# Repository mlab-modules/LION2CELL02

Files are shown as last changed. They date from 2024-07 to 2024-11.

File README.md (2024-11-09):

# LION2CELL02 - Dual-cell Li-Ion BMS with I2C interface and USB-C charging.

The LION2CELL02 module is designed to manage the charging and protection of the 2-cell Li-Ion battery stack. It incorporates advanced safe and efficient battery management features, utilizing the BQ40Z50-R2 fuel gauge and BQ25792 battery charger ICs.

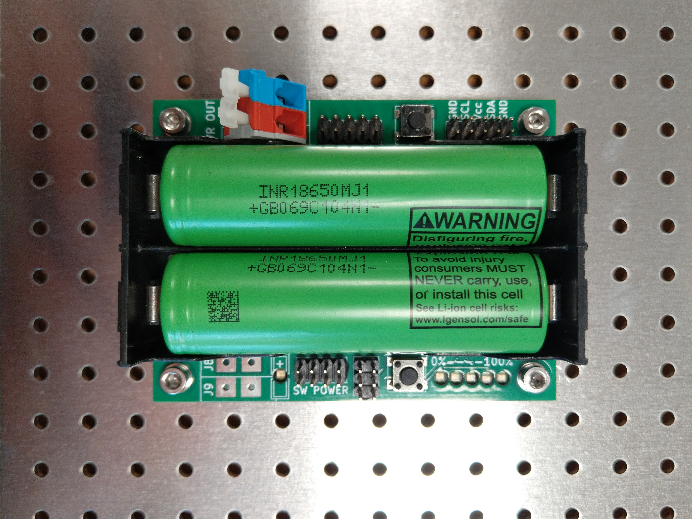
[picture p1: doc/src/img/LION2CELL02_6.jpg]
LION2CELL02 mounted on MLAB base


## Features

The LION2CELL02 module include USB-C connector for quick charge connection. This allows for easy integration with USB-C power sources.

### BQ40Z50-R2 - Fuel Gauge

- Utilizes Impedance Track™ technology for accurate charge measurement.
- High-side protection N-FETs control.
- Integrated cell balancing during charging or at rest.
- Programmable protection features (voltage, current, temperature, charge timeout).
- JEITA, enhanced charging, and adaptive charging algorithms.
- Supports TURBO Mode 2.0 and Battery Trip Point (BTP).
- LED display for battery status.
- SMBus v1.1 interface for communication with the charger and host systems.

### BQ25792 Battery Charger

- Supports USB BC 1.2 charging standard.
- High-efficiency buck-boost charging for Li-Ion batteries.
- Programmable input current, charge current, and charge voltage.
- Integrated power path management.
- Protection features including overvoltage, undervoltage, overcurrent, and thermal protection.
- Low quiescent current for extended battery life.

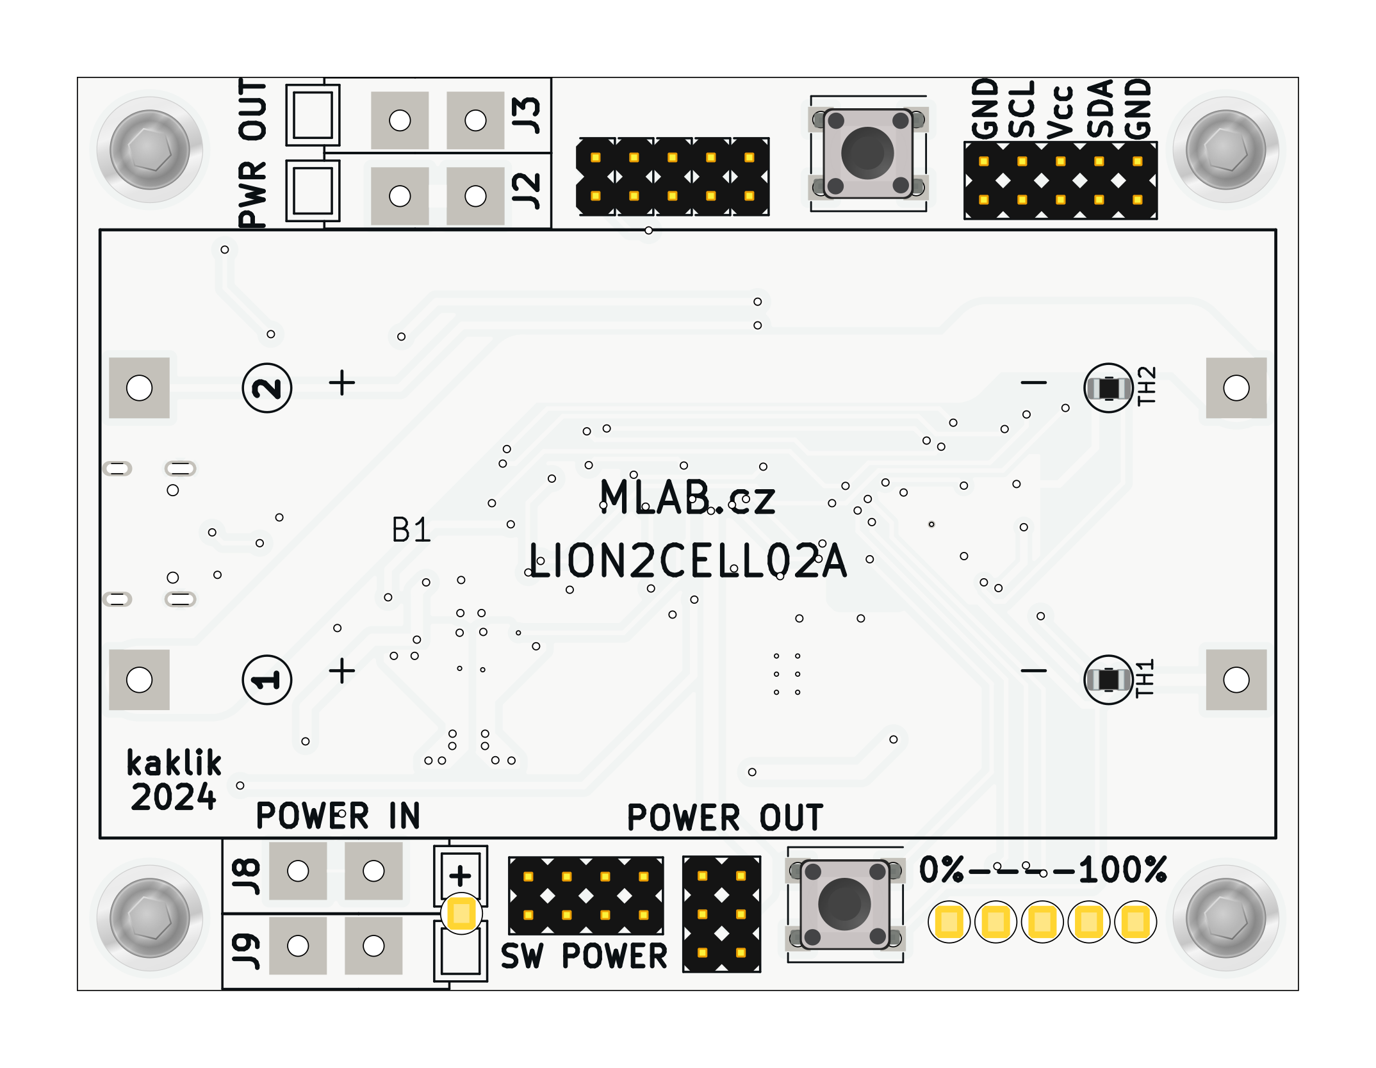
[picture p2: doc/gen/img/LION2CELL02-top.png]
LION2CELL02 top


## Power Delivery

The module supports BC 1.2 for charging. For the full USB Power Delivery (PD) support, an external USB PD controller is required. The MLAB [USBPDSINK01](https://www.mlab.cz/module/USBPDSINK01/) module can be used to enable PD functionality.

## Usage Instructions

1. Equip the LION2CELL02 module with pair of the suitable 16850 Li-Ion batteries.
2. Connect a USB-C power source to the module. For standard charging, ensure the power source complies with BC 1.2.
3. For USB PD, connect the USBPDSINK01 module to enable PD negotiation and charging.
4. Monitor the LED indicators for battery and charging status.
5. Connect to an MCU and use I2C/smbus for advanced features. 

## Safety and Protection

- The module includes multiple layers of protection for voltage, current, and temperature to ensure safe operation.
- Integrated cell balancing ensures equal charging across all cells, preventing overcharge and extending battery life.

## Applications

- UPS/battery backup systems
- Stand-alone measurement devices
- Scientific equipment

## Additional Resources

For further information, refer to the datasheets:
- [BQ40Z50-R2 Datasheet](https://www.ti.com/product/BQ40Z50-R2)
- [BQ25792 Datasheet](https://www.ti.com/product/BQ25792)

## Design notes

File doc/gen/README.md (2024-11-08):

# PCB

Board size: 80.77x60.45 mm (3.18x2.38 inches)

- This is the size of the rectangle that contains the board
- Thickness: 1.6 mm (63 mils)
- Material: FR4
- Finish: None
- Layers: 2
- Copper thickness: 35 µm

Solder mask: TOP / BOTTOM

- Color: Green

Silk screen: TOP / BOTTOM

- Color: White

Stackup:

| Name | Type | Color | Thickness [µm]| Material | Er | Loss tan |
|---|---|---|---|---|---|---|
| F.SilkS | Top Silk Screen | | | | | |
| F.Mask | Top Solder Mask | | 10 | | | |
| F.Cu | copper | | 35 | | | |
| dielectric 1 | core | | 1510 | FR4 | 4.5 | 0.020 |
| B.Cu | copper | | 35 | | | |
| B.Mask | Bottom Solder Mask | | 10 | | | |
| B.Paste | Bottom Solder Paste  | | | | | |
| B.SilkS | Bottom Silk Screen | | | | | |

# Important sizes

Clearance: 0.2 mm (8 mils)

Track width: 0.2 mm (8 mils)

- By design rules: 0.2 mm (8 mils)

Drill: 0.3 mm (12 mils)

- Vias: 0.3 mm (12 mils) [Design: 0.3 mm (12 mils)]
- Pads: 0.3 mm (12 mils)
- The above values are real drill sizes, they add 0.1 mm (4 mils) to plated holes (PTH)

Via: 0.4/0.2 mm (16/8 mils)

- By design rules: 0.4/0.2 mm (16/8 mils)
- Micro via: yes [0.2/0.1 mm (8/4 mils)]
- Buried/blind via: yes
- Total: 91 (thru: 88 buried/blind: 0 micro: 3)

Outer Annular Ring: 0.05 mm (2 mils)

- By design rules: 0.1 mm (4 mils)

Eurocircuits class: 6F
- Using min drill 0.15 mm for an OAR of 0.13 mm

# General stats

Components count: (SMD/THT)

- Top: 2/19 (SMD + THT)
- Bottom: 83/0 (SMD)

Defined tracks:

- 0.2 mm (8 mils)
- 0.25 mm (10 mils)
- 0.3 mm (12 mils)
- 0.4 mm (16 mils)
- 0.5 mm (20 mils)
- 0.6 mm (24 mils)
- 0.8 mm (31 mils)
- 1.5 mm (59 mils)

Used tracks:

- 0.2 mm (8 mils) (195) defined: yes
- 0.3 mm (12 mils) (330) defined: yes
- 0.4 mm (16 mils) (15) defined: yes
- 0.5 mm (20 mils) (103) defined: yes
- 0.6 mm (24 mils) (2) defined: yes
- 0.8 mm (31 mils) (41) defined: yes
- 1.0 mm (39 mils) (52) defined: no
- 1.5 mm (59 mils) (1) defined: yes
- 4.5 mm (177 mils) (6) defined: no

Defined vias:

Used vias:

- 0.4/0.2 mm (16/8 mils) (Count: 3, Aspect: 4.0 A) defined: no
- 0.8/0.4 mm (31/16 mils) (Count: 88, Aspect: 2.0 A) defined: no

Holes (excluding vias):

- 0.2 mm (8 mils) (7)
- 0.65 mm (26 mils) (2)
- 0.89 mm (35 mils) (34)
- 1.0 mm (39 mils) (8)
- 1.3 mm (51 mils) (8)
- 1.6 mm (63 mils) (4)
- 2.7 mm (106 mils) (6)
- 3.0 mm (118 mils) (4)

Oval holes:

- 0.6x1.4 mm (24x55 mils) (2)
- 0.6x1.7 mm (24x67 mils) (2)

Drill tools (including vias and computing adjusts and rounding):

- 0.3 mm (12 mils) (10)
- 0.5 mm (20 mils) (88)
- 0.65 mm (26 mils) (2)
- 0.7 mm (28 mils) (4)
- 1.0 mm (39 mils) (34)
- 1.1 mm (43 mils) (8)
- 1.4 mm (55 mils) (8)
- 1.7 mm (67 mils) (4)
- 2.7 mm (106 mils) (6)
- 3.1 mm (122 mils) (4)

Solder paste stats:

Using a paste with 87.75 % alloy, that has an specific gravity for the alloy of 7.4 g/cm³
and 1.0 g/cm³ for the flux. This paste has an specific gravity of  4.15 g/cm³.

The stencil thickness is  0.12 mm.

| Side | Pads with paste | Area [mm²] | Paste [g] |
|---|---|---|---|
| Top | 4 | 5.51 | 0.03 |
| Bottom | 254 | 338.60 | 1.69 |
| Total  | 258 | 344.11 | 1.71 |

Note: this is just an approximation to the theoretical value. Margins of the solder mask and waste aren't computed.

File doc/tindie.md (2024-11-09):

### MLAB LION2CELL02 - Dual-Cell Li-Ion Battery Management Module

### What is it?

The **MLAB LION2CELL02** is a high-efficiency dual-cell battery management system (BMS) designed to charge and protect a two-cell Li-Ion battery stack. Featuring an I2C interface and a USB-C charging port, the LION2CELL02 integrates easily into systems requiring robust power management. The module is compatible with standard USB BC 1.2 sources.

The LION2CELL02 is pre-configured for **INR18650MJ1** cells, ensuring optimal performance and battery health.

### Why did you make it?

This module was created to simplify the power management and protection requirements where single-cell Li-Ion battery setups are not enougth. It’s tailored to applications requiring reliable charging, safety, and monitoring features, which are essential in embedded systems like IoT devices, portable instruments, and backup power solutions. 

### What makes it special?

- **Dual-cell support and protection**: Charger and Gas-gauge both independently manages charging for two Li-Ion cells, with integrated protection for voltage, current, and temperature.
- **I2C communication**: Allows seamless integration with microcontroller systems for real-time battery status.
- **High-efficiency charging**: Includes the BQ25792 high-efficiency buck-boost charger, ensuring fast and reliable charging from USB-C sources.
- **Advanced cell balancing**: The BQ40Z50-R2 fuel gauge features Impedance Track™ technology for precise capacity measurement and cell balancing, extending battery lifespan.
- **Flexible Power Delivery (PD)**: Compatible with USB BC 1.2 and offers optional USB PD support via an external controller.

### Key Features

- **USB-C Charging**: Supports USB BC 1.2 with an optional external PD controller.
- **Integrated Protections**: Includes overvoltage, undervoltage, overcurrent, and thermal protections.
- **High Precision Fuel Gauge**: Impedance Track™ technology provides real-time capacity and state-of-charge data.
- **I2C Interface**: Connects easily to MCUs for monitoring battery voltage, current, and temperature.
- **LED Indicators**: Visual indicators display charge level and fault conditions.

### Technical Specifications

- **Battery Type**: Li-Ion (configured for INR18650MJ1 cells)
- **Cells Supported**: 2 cells (2S configuration)
- **Charger IC**: Texas Instruments BQ25792
- **Fuel Gauge IC**: Texas Instruments BQ40Z50-R2
- **Input Voltage**: 3.6V to 20V (USB-C)
- **Output Current**: Up to 5A (charging), 3A (USB OTG mode)
- **Communication**: I2C (compatible with SMBus v1.1)
- **Protections**: Overvoltage, undervoltage, overcurrent, overtemperature, cell balancing
- **Dimensions**: Fits standard 6x8 MLAB module footprint

For additional details and configuration options, refer to the datasheets for [BQ40Z50-R2](https://www.ti.com/product/BQ40Z50-R2) and [BQ25792](https://www.ti.com/product/BQ25792).

### Included

- LION2CELL02 module pre-configured
- Two INR18650MJ1 Li-ion cells

### Use Cases

- [Stratospheric baloons](https://github.com/ODZ-UJF-AV-CR/FIK-6)

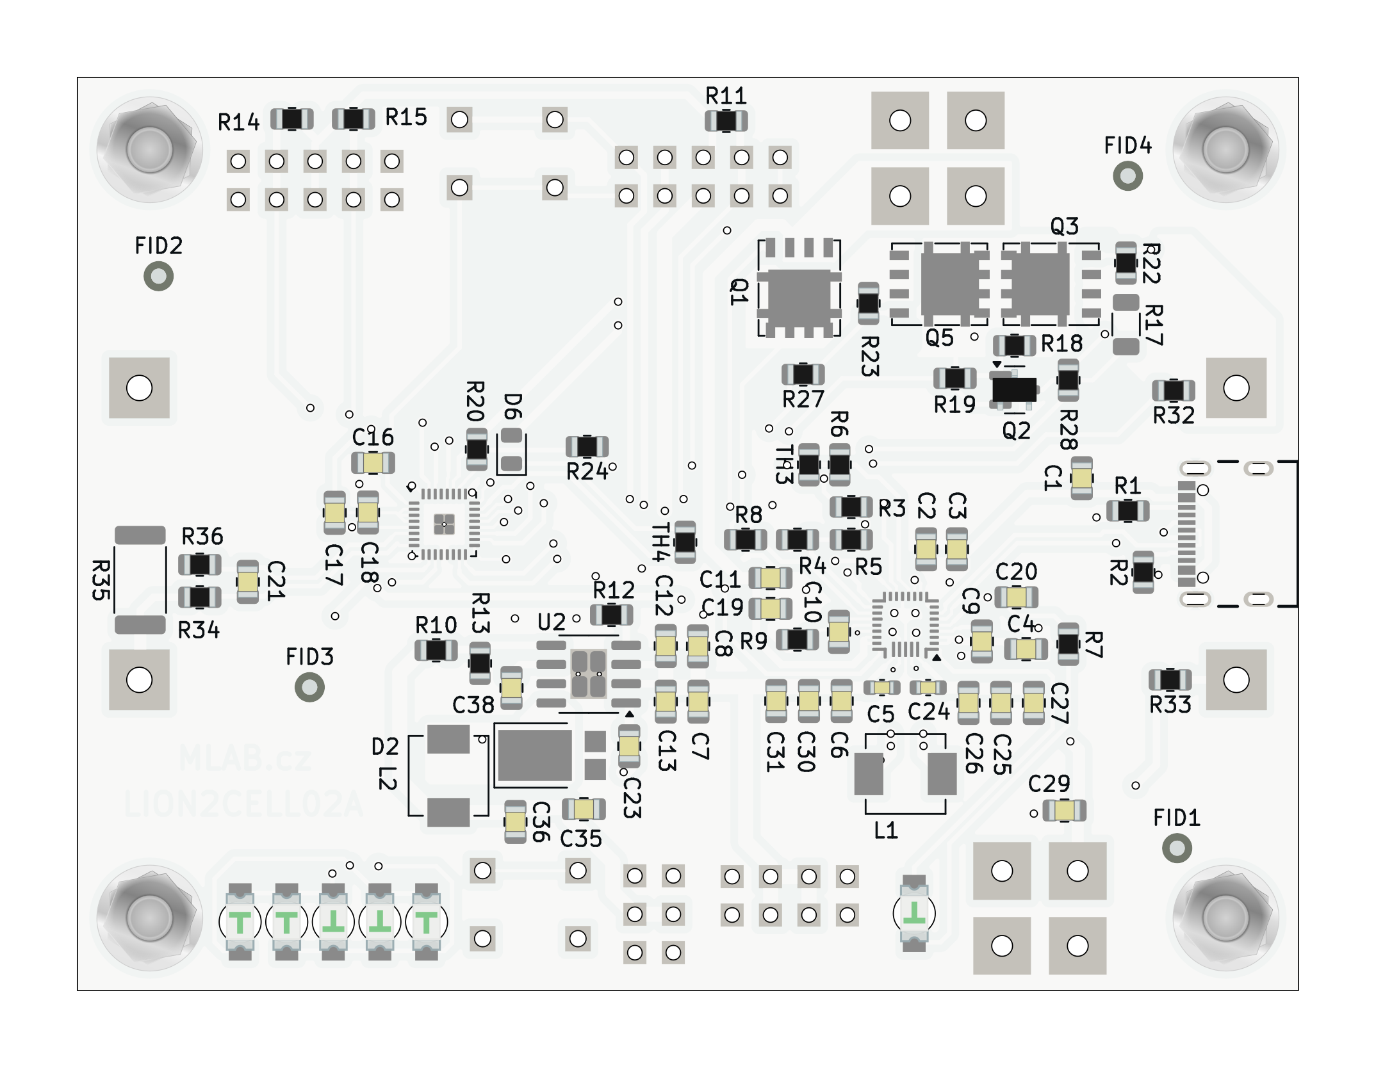
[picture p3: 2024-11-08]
doc/gen/img/LION2CELL02-bottom.png

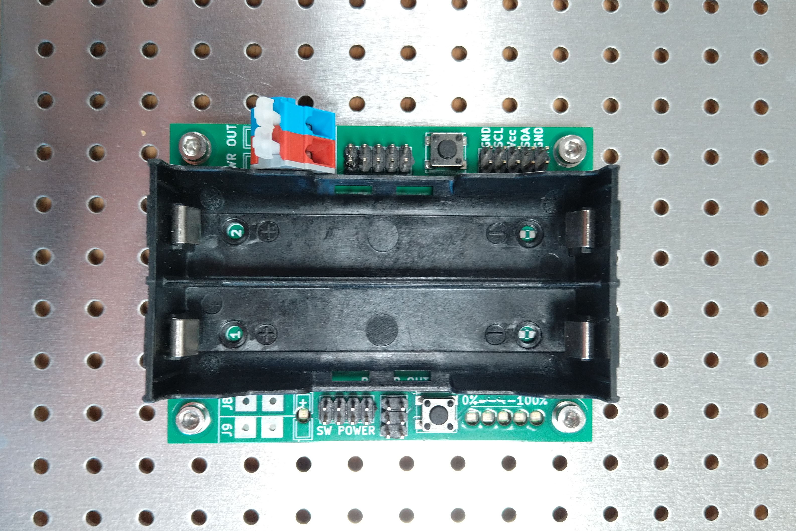
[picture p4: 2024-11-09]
doc/src/img/LION2CELL02_3.jpg

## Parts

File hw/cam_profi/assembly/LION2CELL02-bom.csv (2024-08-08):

Component | Description | Part | References | Value | Footprint | Quantity Per PCB | Datasheet | ust_id | lcsc | mfpn | mpn | manufacturer_part_number
1 |  | battery-2s | B1 | 18650 | BAT_BK-18650-PC4_no_screws | 1 |  | 5c70984412875079b91f87e9
2 | Unpolarized capacitor | C | C38 | 22nF | C_0805_2012Metric | 1 | ~ | 5c70984712875079b91f8b4a
3 | Unpolarized capacitor, small symbol | C_Small | C9C10 | 47nF | C_0805_2012Metric | 2 | ~ | 65482046462c6d9e72056b98
4 | Unpolarized capacitor, small symbol | C_Small | C1C2C17C18C21C23C29 | 100nF | C_0805_2012Metric | 7 | ~ | 5c70984712875079b91f8b4c | C1525 | C0805 1u | C0805 1u
5 | Unpolarized capacitor, small symbol | C_Small | C5C24 | 100nF | C_0603_1608Metric | 2 | ~ | 5c70984812875079b91f8bf2
6 | Unpolarized capacitor | C | C12C35 | 1uF | C_0805_2012Metric | 2 | ~ | 5c70984712875079b91f8b6f
7 | Unpolarized capacitor, small symbol | C_Small | C16 | 2.2uF | C_0805_2012Metric | 1 | ~ | 5c70984712875079b91f8b51
8 | Unpolarized capacitor, small symbol | C_Small | C20 | 4u7 | C_0805_2012Metric | 1 | ~ | 5e3ff8fc1287502a33bad7a3
9 | Unpolarized capacitor, small symbol | C_Small | C3C4C6C7C8C11C13C19C25C26C27C30C31C36 | 10u | C_0805_2012Metric | 14 | ~ | 5c70984712875079b91f8b53 607c1245128750769ee58ca7
10 | 75V 0.15A Fast switching Diode, SOD-323 | 1N4148WS | D6 | 1N4148WS | D_0805_2012Metric | 1 | https://www.vishay.com/docs/85751/1n4148ws.pdf | 5c70984512875079b91f88c5
11 | Light emitting diode | LED | D1D3D4D5D7D8 | LED | LED_1206 | 6 | ~ | 5c70984412875079b91f8892
12 | Schottky diode | D_Schottky | D2 | PDS760-13 | D_PowerDI-5 | 1 | ~ | 6087aaaf128750769ee58fb7
13 |  | CONN1_1 | J2J3J8J9 | CONN1_1 | WAGO256 | 4
14 | 1x02 2.54 mm pitch header | HEADER_1x02 | J11 | HEADER_1x02 | Straight_2x01 | 1
15 | 2x01 2.54 mm pitch header, 2 pins next to each other are connected | HEADER_2x01_PARALLEL | J6J7J10 | HEADER_2x01_PARALLEL | Straight_2x01 | 3
16 | 2x03 2.54 mm pitch header, 2 pins next to each other are connected | HEADER_2x03_PARALLEL | J5 | HEADER_2x03_PARALLEL | Straight_2x03 | 1
17 | 2x05 2.54 mm pitch header, 2 pins next to each other are connected | HEADER_2x05_PARALLEL | J12 | HEADER_2x05_PARALLEL | Straight_2x05 | 1
18 |  | JUMP_4X2 | J4 | JUMP_4X2 | Straight_2x04 | 1
19 | USB 2.0-only Type-C Receptacle connector | USBC_USB4105-GF-A | J1 | USBC_USB4105-GF-A | USBC GCT_USB4105-GF-A | 1 |  | 5fa0f94612875025b397795e |  | USB4105-GF-A | USB4105-GF-A
20 | Jumper, 2-pole, open | Jumper_2_Open | JP1 | Jumper_2_Open | Straight_2x01 | 1 | ~
21 | Inductor, small symbol | L_Small | L1L2 | 2.2uH | L_Vishay_IHLP-2020 | 2 | https://www.vishay.com/docs/34563/ihlp-2020cz-8a.pdf | 669e8efe6fdfe6f54e2eb7e6
22 | -4.0A Id, -30V Vds, P-Channel MOSFET, SOT-23 | AO3401A | Q2 | AP2305AGN-HF-3 | SOT-23 | 1 | https://www.tme.eu/Document/fc64476bcfec1f3af35a324c08c5f351/AP2305AGN-3.pdf | 5c70984712875079b91f8af1
23 | N-MOSFET transistor, source/gate/drain | Q_NMOS_SGD | Q1Q3Q5 | DMTH3002LPS | D_POWERDI5060-8_6.0x5.1mm_P1.27mm | 3 | https://eu.mouser.com/datasheet/2/115/DIOD_S_A0003132884_1-2542222.pdf | 669990696fdfe6f54e2eb28a |  |  |  | DMT31M7LPS-13
24 | Resistor, small symbol | R_Small | R35 | 2mR | R_2512_6332Metric | 1 | https://www.tme.eu/Document/9eb17c5caf6d68fb7c80b751e0adae3a/LR12.pdf | 669ba41c6fdfe6f54e2eb51d
25 | Resistor, small symbol | R_Small | R8R20R32R33R34R36 | 100 | R_0805_2012Metric | 6 | ~ | 5c70984512875079b91f8977 | C17408 C25076
26 | Resistor, small symbol | R_Small | R17 | 300R | R_1206_3216Metric | 1 | ~ | 5c70984712875079b91f8ab8
27 | Resistor, small symbol | R_Small | R7 | 2k2 | R_0805_2012Metric | 1 | ~ | 5c70984612875079b91f8990
28 | Resistor, small symbol | R_Small | R1R2R19R27R28 | 5k1 | R_0805_2012Metric | 5 | ~ | 5fa0fc3e12875025b3977997 | C25905
29 | Resistor, small symbol | R_Small | R5 | 5.24k | R_0805_2012Metric | 1 | ~ | 66a159d36fdfe6f54e2ebef5
30 | Resistor, small symbol | R_Small | R9 | 8k2 | R_0805_2012Metric | 1 | ~ | 5c70984612875079b91f899c
31 | Resistor, small symbol | R_Small | R11R13R14R15R24 | 10k | R_0805_2012Metric | 5 | ~ | 5c70984612875079b91f899f | C25744
32 | Resistor | R | R12 | 15k | R_0805_2012Metric | 1 | ~ | 5c70984712875079b91f8b6a
33 | Resistor, small symbol | R_Small | R6 | 30.31k | R_0805_2012Metric | 1 | ~ | 66a15a4a6fdfe6f54e2ebf1b
34 | Resistor | R | R10 | 44k2 | R_0805_2012Metric | 1 | ~ | 669ebdcc6fdfe6f54e2eb869
35 | Resistor, small symbol | R_Small | R4 | 100k | R_0805_2012Metric | 1 | ~ | 639ed3d540d28a66c9e88a9e
36 | Resistor, small symbol | R_Small | R3 | 127k | R_0805_2012Metric | 1 | ~ | 66a1559d6fdfe6f54e2ebeaa
37 | Resistor, small symbol | R_Small | R18R22R23 | 10M | R_0805_2012Metric | 3 | ~ | 5c70984712875079b91f8aae | C26082
38 | Push button switch, generic, two pins | SW_Push | SW1SW2 | SW_Push | SW_PUSH_SMALL | 2 | ~ | 5c70984712875079b91f8ad2
39 | Temperature dependent resistor, negative temperature coefficient | Thermistor_NTC | TH1TH2TH3TH4 | NCP21XV103J03RA | R_0805_2012Metric | 4 | ~ | 5c70984712875079b91f8ac5 | C279801
40 |  | BQ25792RQMR | U1 | BQ25792RQMR1 | Texas_RQM0029A_VQFN-HR-28_4x4mm_P0.5mm | 1 | https://www.ti.com/lit/ds/symlink/bq25792.pdf | 66a15cdb6fdfe6f54e2ebf66
41 |  | BQ40z50-R2 | U3 | BQ40z50-R2 | Texas_RSM0032A_VQFN-32-4.1x4.1-EP-1.4 | 1 | http://www.ti.com/lit/ds/symlink/bq40z50-r2.pdf | 66a15dd06fdfe6f54e2ebf93 | C179743
42 |  | LMR14050 | U2 | LMR14050 | SOIC-8-1EP_3.9x4.9mm_P1.27mm_EP2.41x3.3mm_ThermalVias | 1 | https://www.ti.com/lit/ds/symlink/lmr14050.pdf | 6087b6ba128750769ee59110

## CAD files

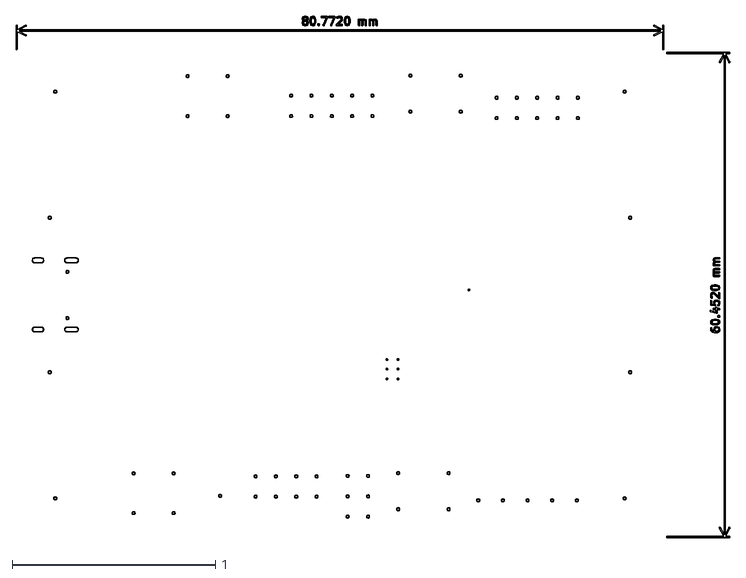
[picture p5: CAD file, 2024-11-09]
doc/gen/dxf/LION2CELL02-User_Comments.dxf
3.51 x 2.56

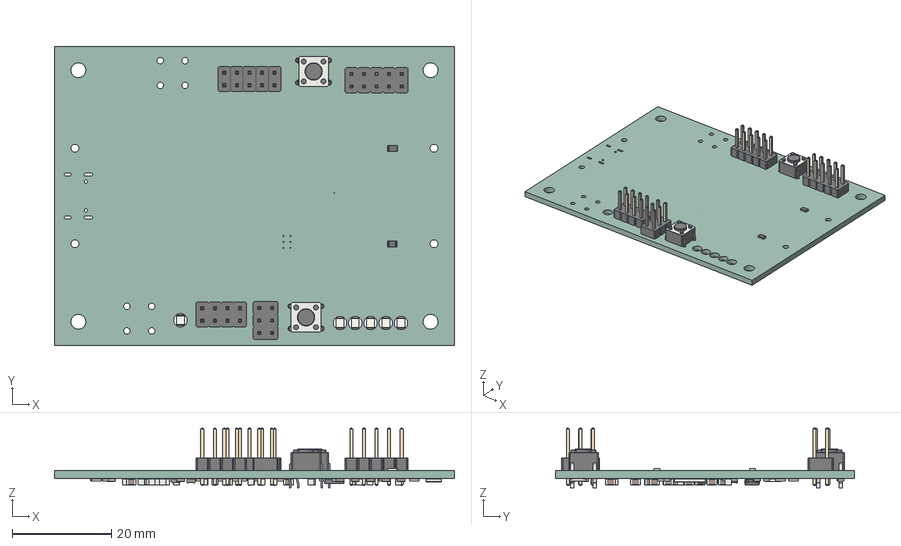
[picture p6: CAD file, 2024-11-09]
doc/gen/LION2CELL02.step
80.8 x 60.5 x 12.0 mm
PinHeader_2x04_P254mm_Vertical
PinHeader_2x01_P254mm_Vertical x 5
PinHeader_2x05_P254mm_Vertical
SW_PUSH_6mm_h4.3mm x 2
PinHeader_2x03_P254mm_Vertical
R_0805_2012Metric x 31
C_0805_2012Metric x 28
C_0603_1608Metric x 2
LED_1206_3216Metric x 6
R_1206_3216Metric
QFN-32-1EP_4x4mm_Pitch0.4mm x 2
R_2512_6332Metric
D_0805
SOT_23
kibot_jwod166m_PCB

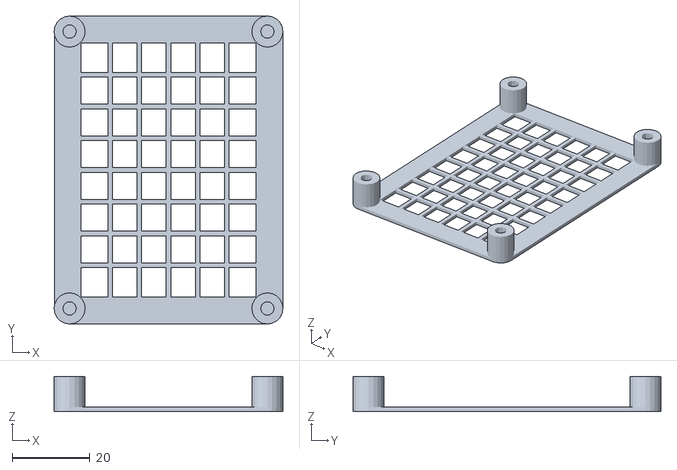
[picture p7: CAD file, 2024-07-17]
hw/cad/6x8MLAB_frame.stl
58.8 x 79.1 x 9.00

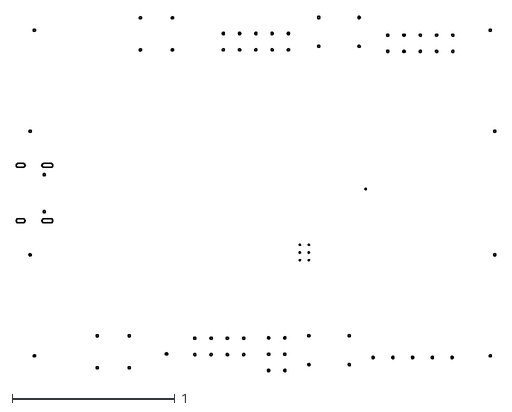
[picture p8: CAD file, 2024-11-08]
doc/gen/dxf/LION2CELL02-User_Drawings.dxf
2.95 x 2.18

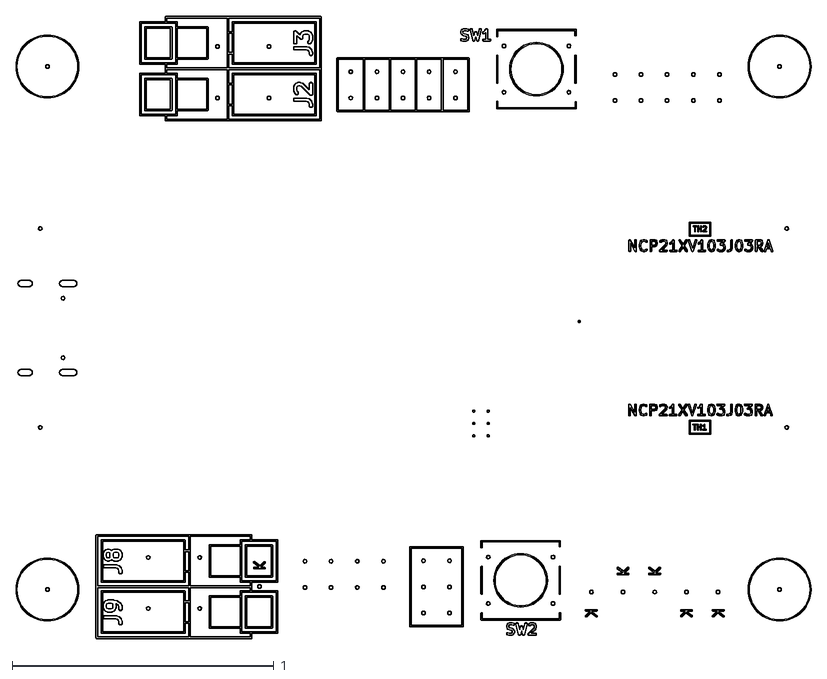
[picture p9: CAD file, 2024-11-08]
doc/gen/dxf/LION2CELL02-F_Fab.dxf
3.04 x 2.38

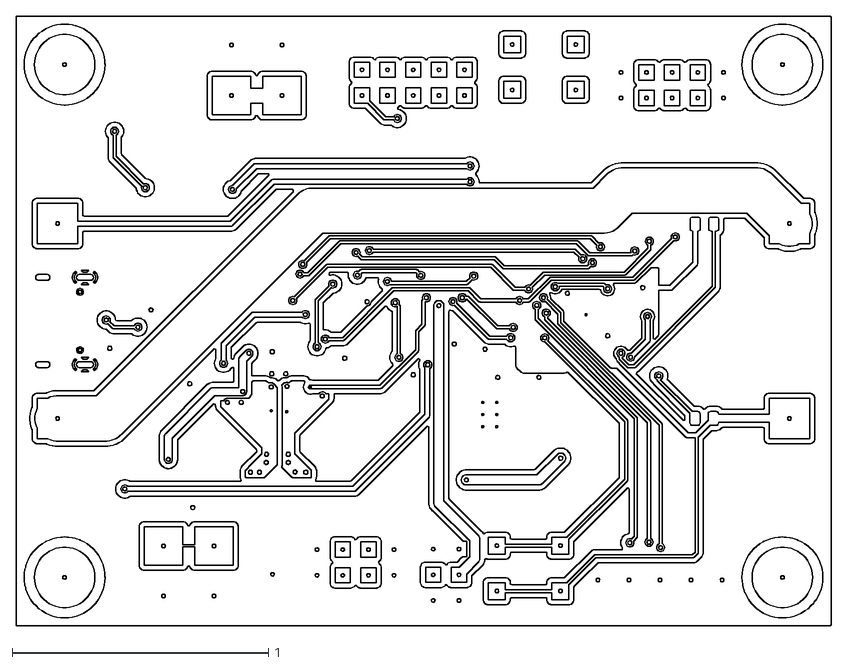
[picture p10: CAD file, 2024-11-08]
doc/gen/dxf/LION2CELL02-F_Cu.dxf
3.18 x 2.38

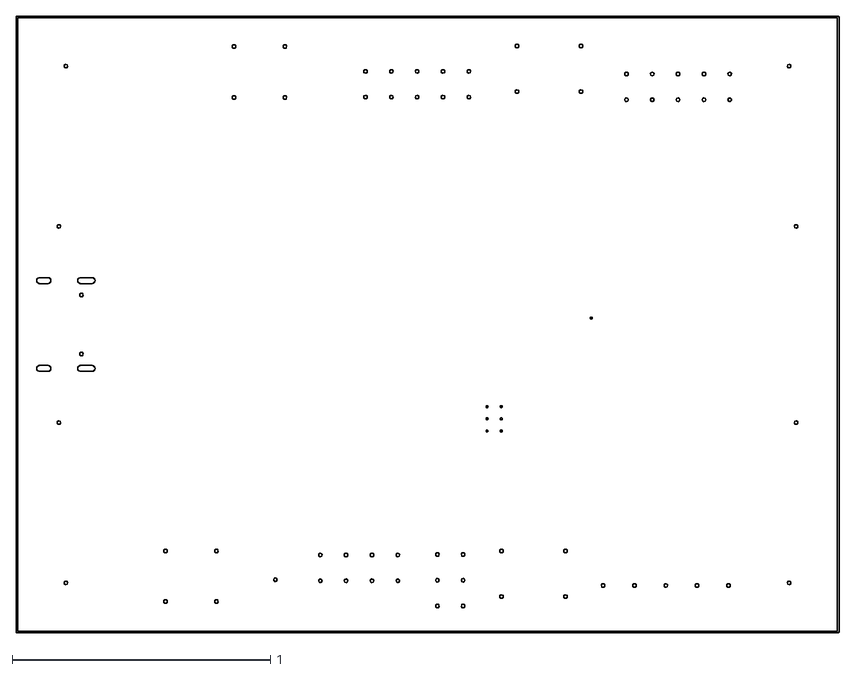
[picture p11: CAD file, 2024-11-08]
doc/gen/dxf/LION2CELL02-Edge_Cuts.dxf
3.19 x 2.39

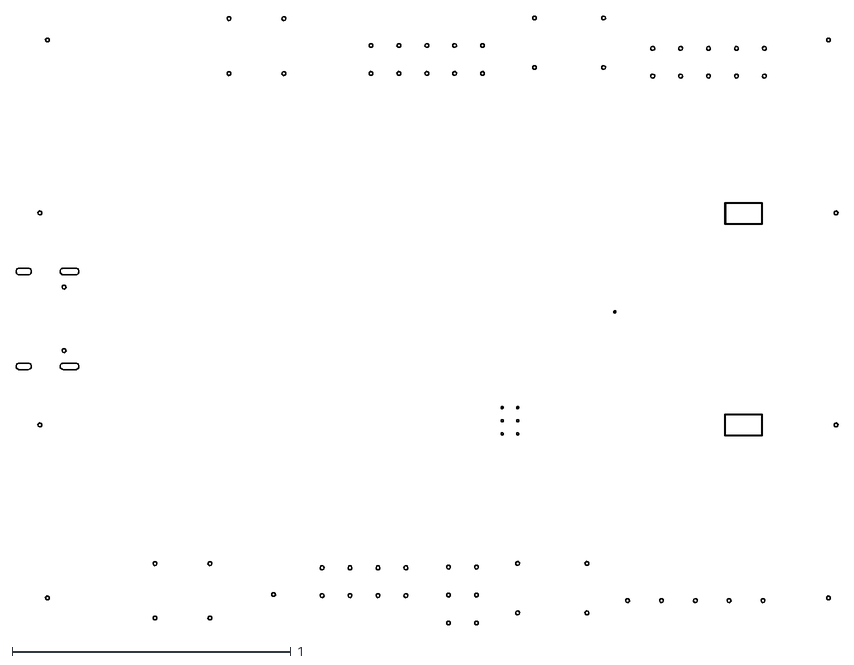
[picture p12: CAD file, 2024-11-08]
doc/gen/dxf/LION2CELL02-F_Courtyard.dxf
2.95 x 2.18

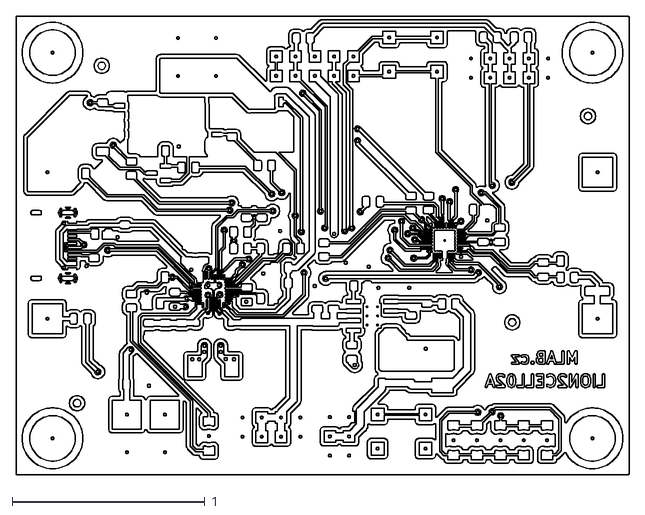
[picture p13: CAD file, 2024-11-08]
doc/gen/dxf/LION2CELL02-B_Cu.dxf
3.18 x 2.38

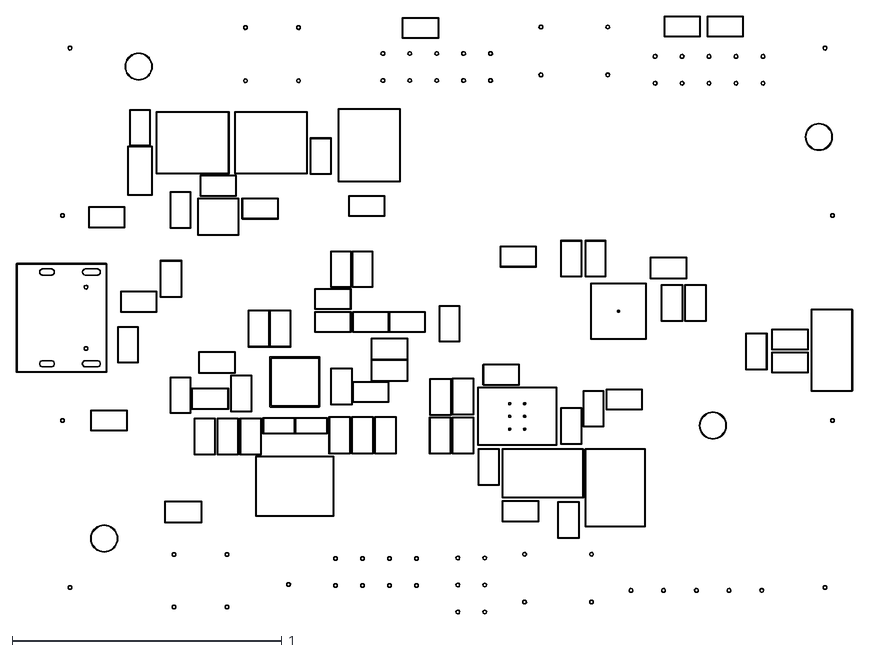
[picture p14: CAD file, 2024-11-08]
doc/gen/dxf/LION2CELL02-B_Courtyard.dxf
3.10 x 2.22

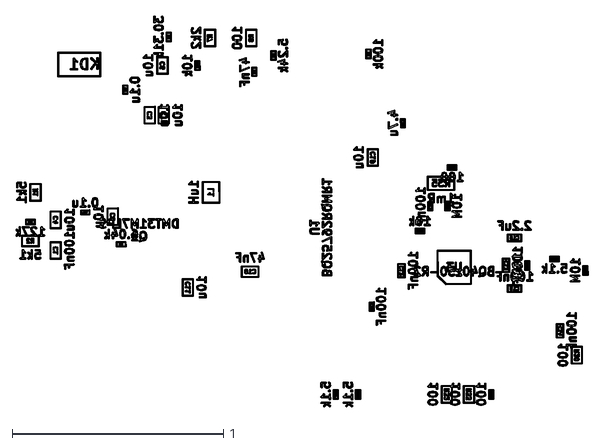
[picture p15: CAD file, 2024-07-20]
doc/gen/dxf/LION2CELL02-B_Fab.dxf
2.71 x 1.85

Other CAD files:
hw/cad/src/6x8MLAB_frame.scad
doc/gen/dxf/LION2CELL02-B_Mask.dxf
doc/gen/dxf/LION2CELL02-B_Paste.dxf
doc/gen/dxf/LION2CELL02-B_Silkscreen.dxf
doc/gen/dxf/LION2CELL02-F_Mask.dxf
doc/gen/dxf/LION2CELL02-F_Silkscreen.dxf

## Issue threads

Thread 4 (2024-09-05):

Tapper charging current limit

kaklik, 2024-09-05:
Při konečné fázi dobíjení, kdy se napětí dvojice akumulátorů blíží 8.4V se ukazuje jako problematické články dobíjet větším proudem než ~500mA. Důvodem je zřejmě vysoký přechodový odpor pouzdra akumulátorů, nebo i dalších cest. Integrovaná dobíječka, která dobíjí v této situaci při standardním nastavení proudem okolo 1A pak dobíjení periodicky přerušuje. Zřejmě proto, že  přechodně dosahuje už cílového napětí akumulátorů, ještě před tím než jsou plně nabité, zřejmě v důsledku přechodových odporů.

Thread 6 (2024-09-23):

System load short damage charger

kaklik, 2024-09-23:
An accidental short circuit on system_load to ground resulted in zero voltage at this output. The reset or power on reset does not have an effect on that situation.

The situation got even worse after enabling the ship-FET during USB-C plugged and battery charging. After that, the changer blinks with the status LED and a cloud of smoke becomes visible from the PCB.

I removed the USB-C plug and cells quickly to stop the situation from getting even worse.

That experience is very strange, because according to the [BQ25792 datasheet](https://www.ti.com/lit/ds/symlink/bq25792.pd). The charger should have System Short Protection (VSYS_SHORT), to avoid that situation.

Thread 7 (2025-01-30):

Possible damage with USB-C plug plugged on side of USB-C board connector

kaklik, 2025-01-30:
Modul se dá poškodit tím, že se USB-C kabel zastrčí omylem pod modul vedle USB-C konektoru.

Nejvhodnější řešení asi je upravit tištěný ochraný díl z původního LION2CELL01, tak aby to nešlo.

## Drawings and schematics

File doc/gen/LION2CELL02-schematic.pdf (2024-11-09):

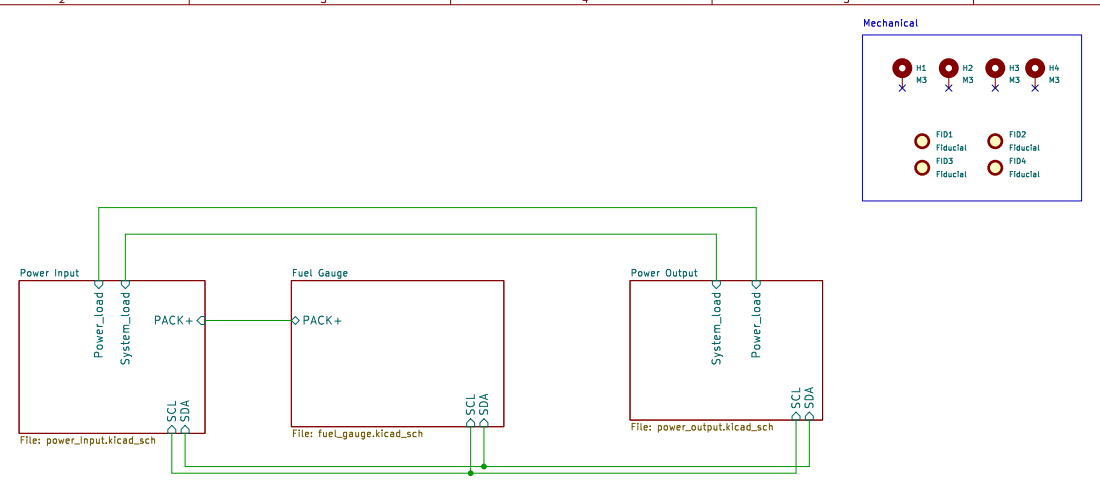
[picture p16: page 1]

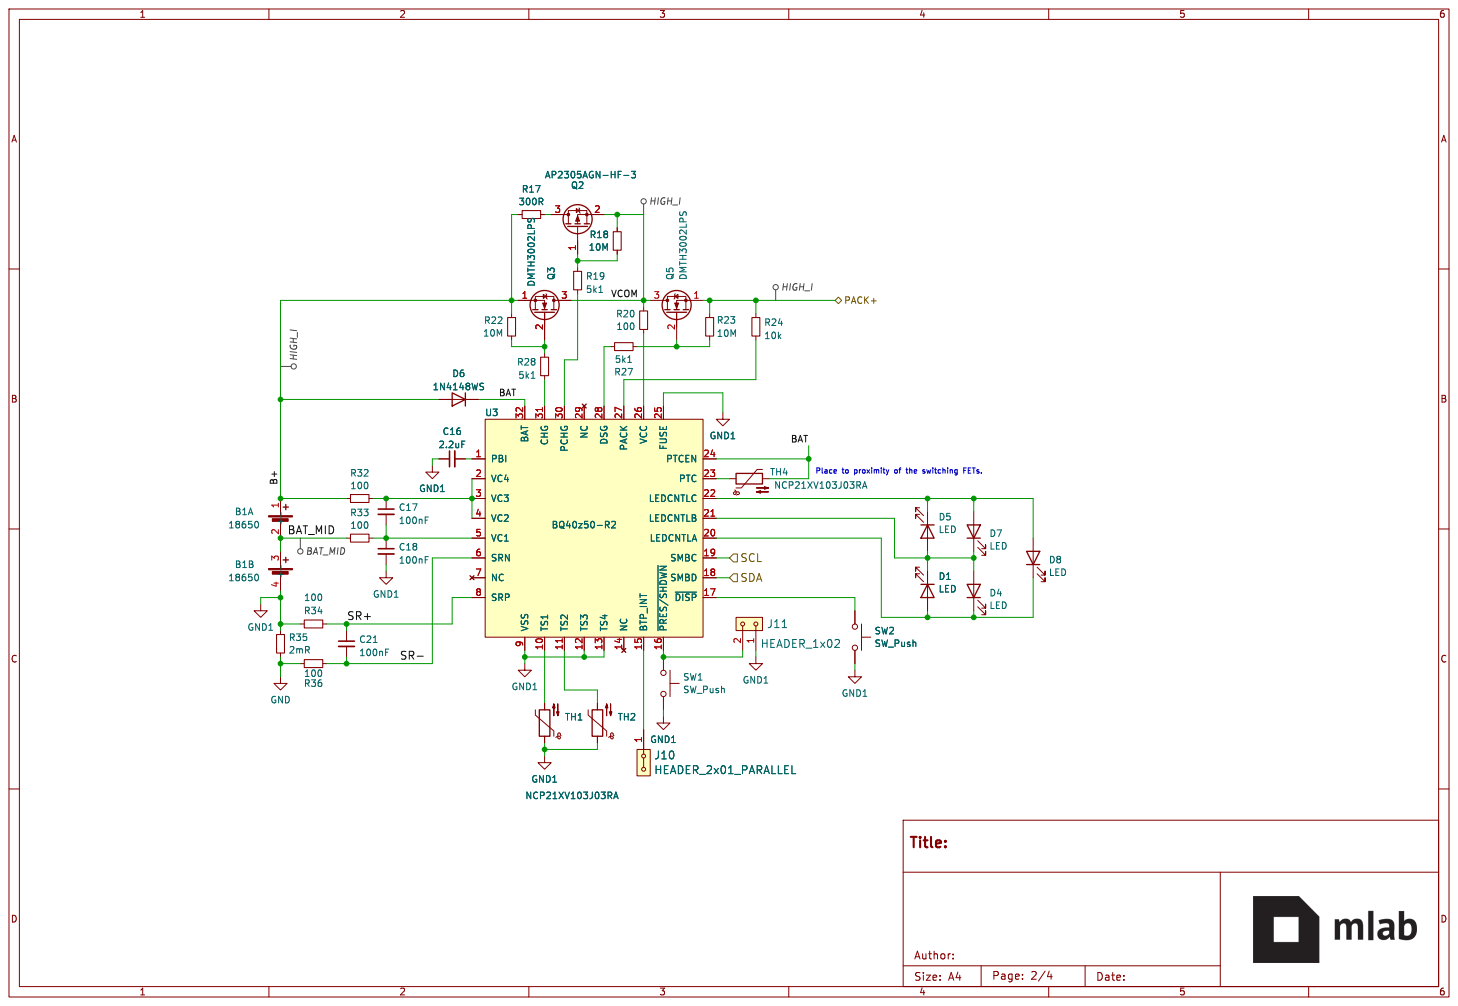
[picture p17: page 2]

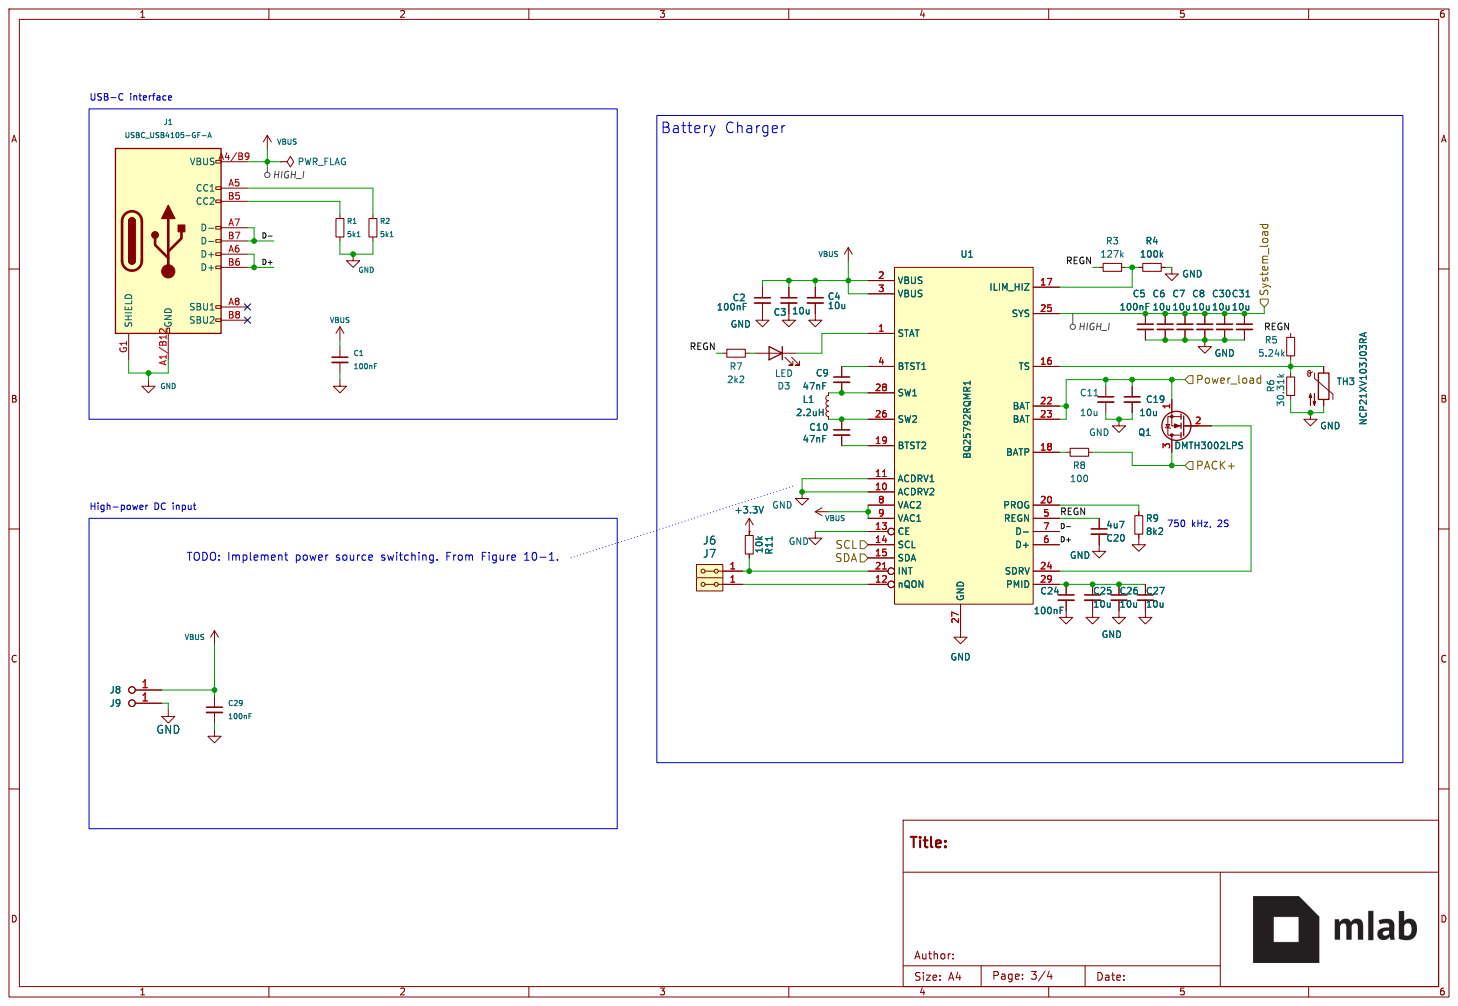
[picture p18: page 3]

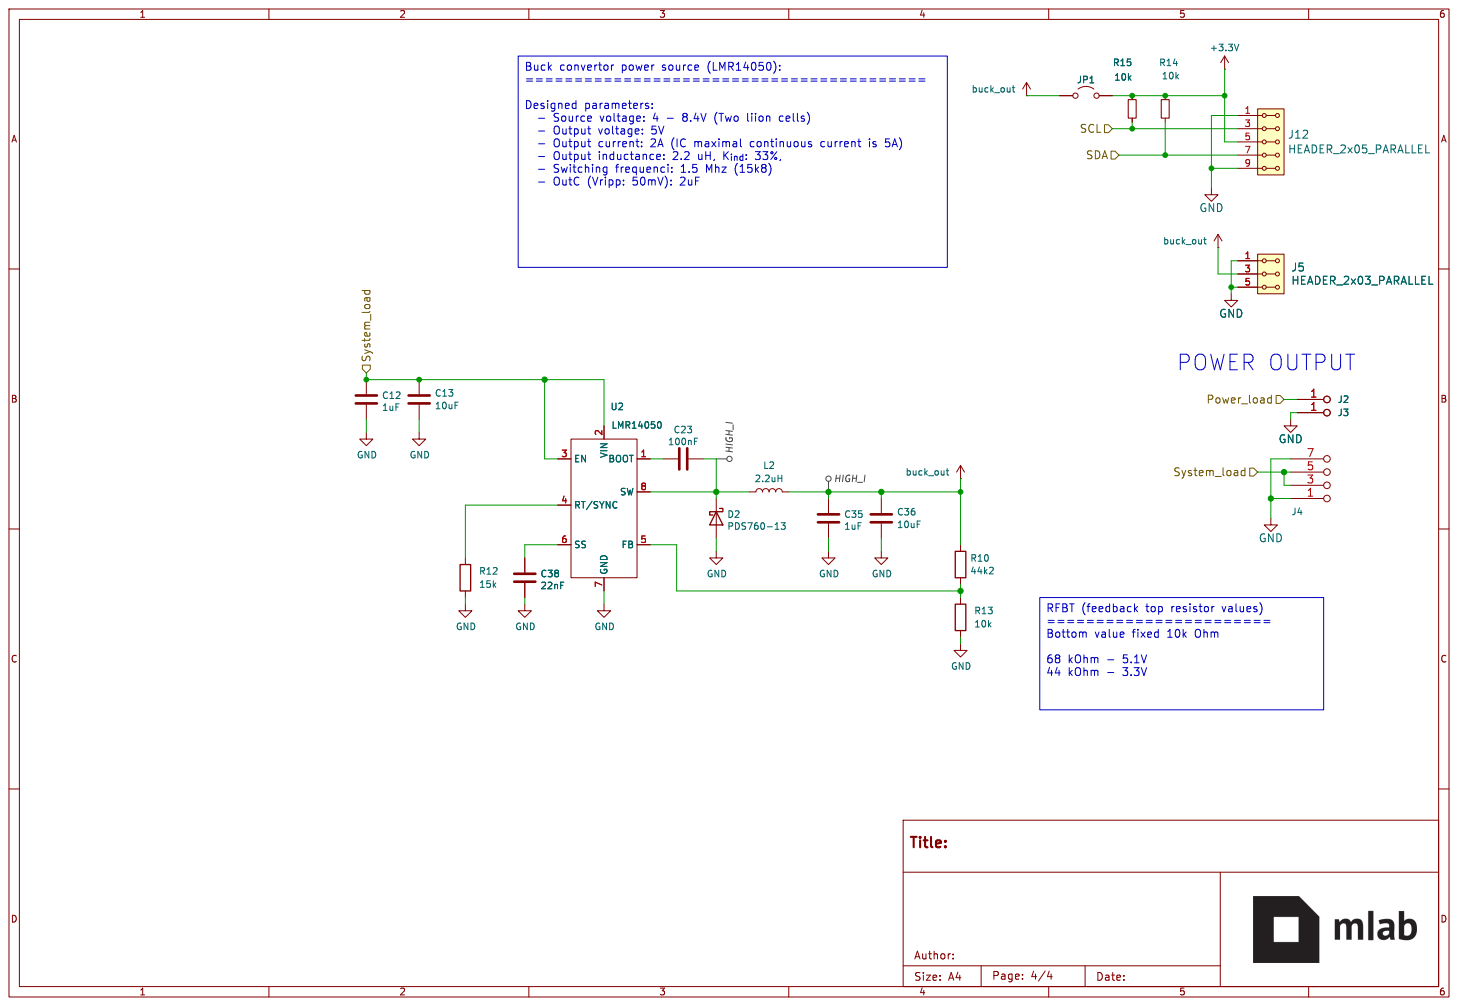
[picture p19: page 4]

2 EN 3 RT/SYNC 4 FB 5 SS 6 GND

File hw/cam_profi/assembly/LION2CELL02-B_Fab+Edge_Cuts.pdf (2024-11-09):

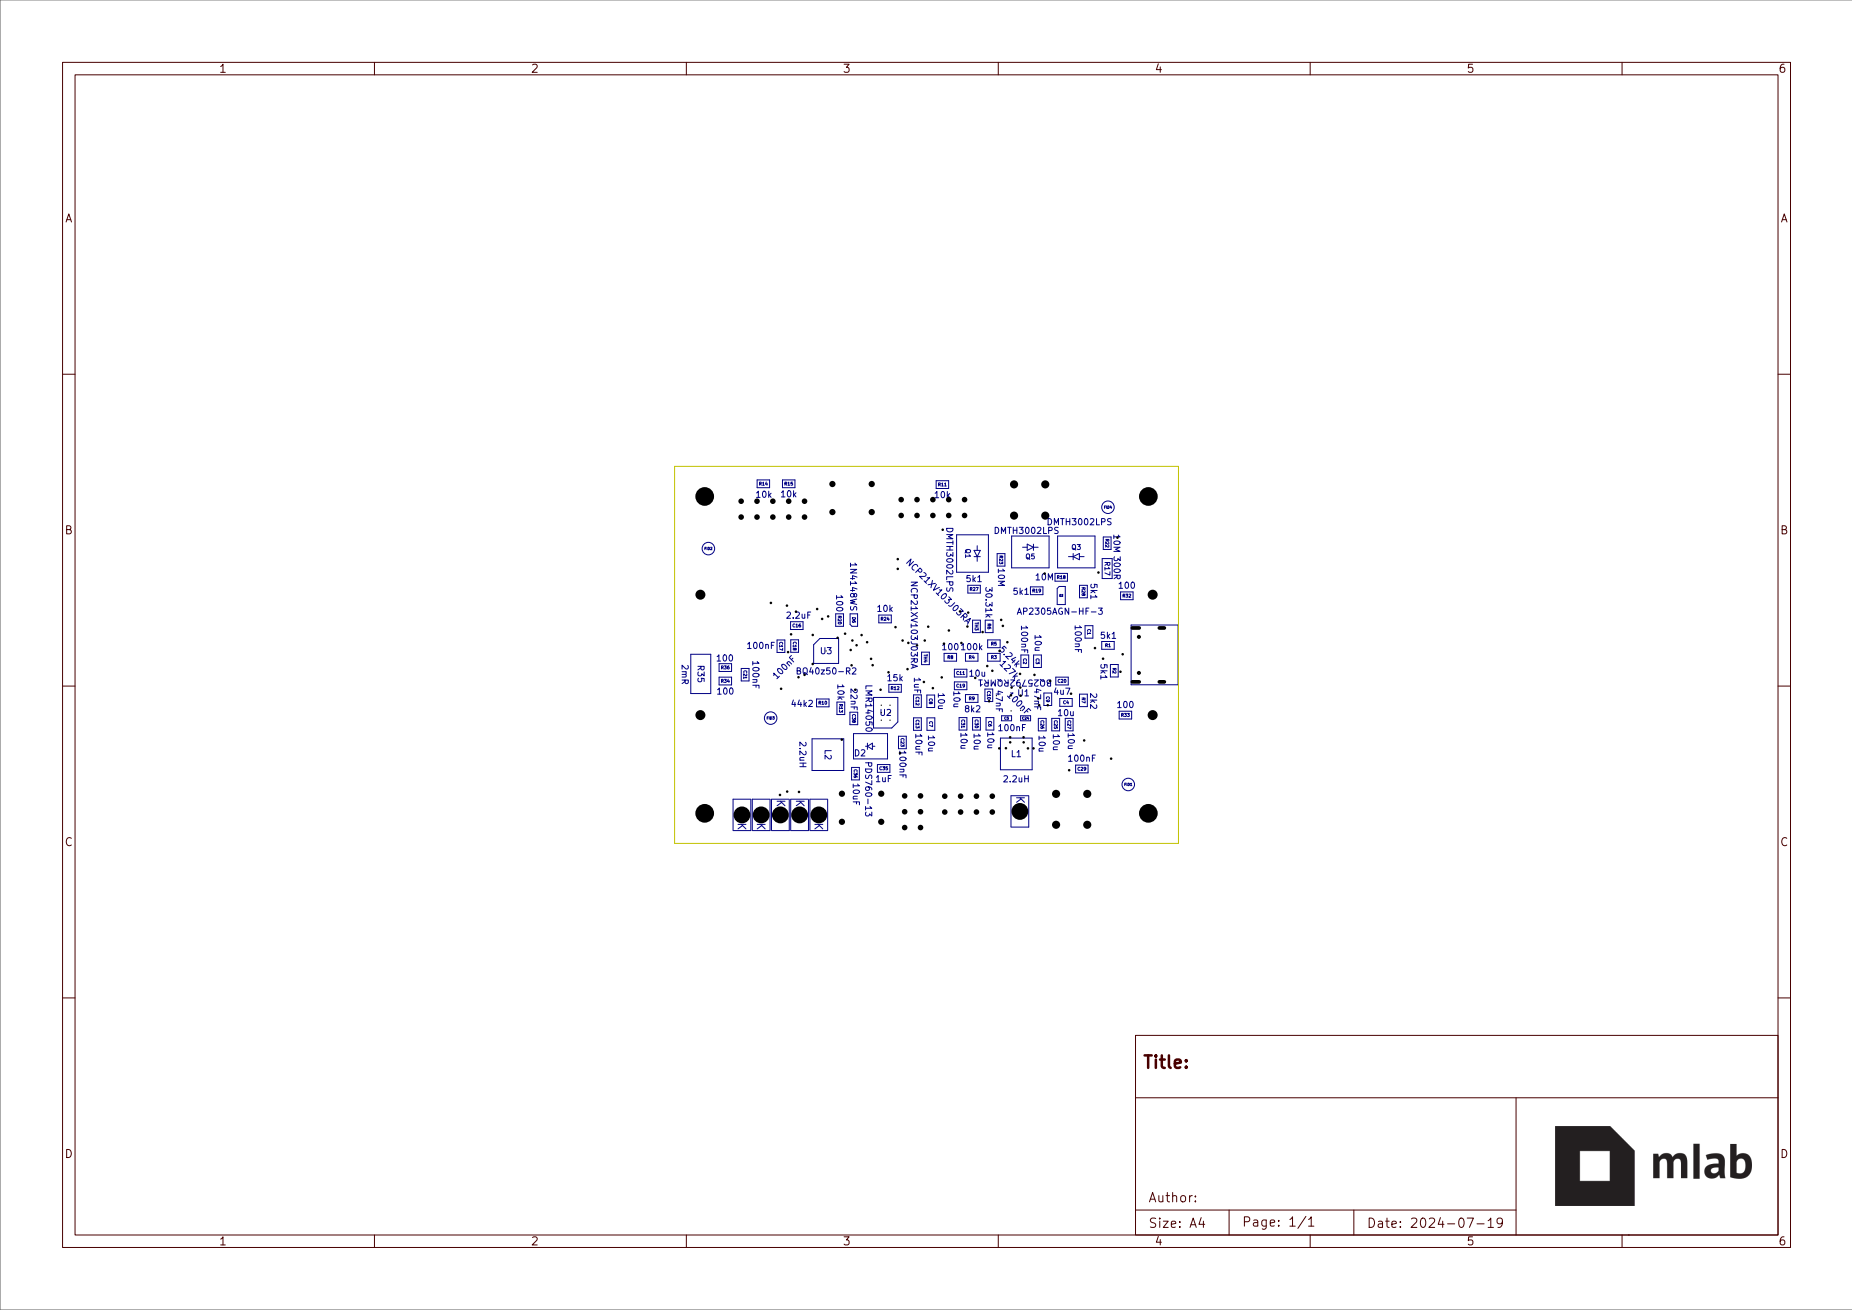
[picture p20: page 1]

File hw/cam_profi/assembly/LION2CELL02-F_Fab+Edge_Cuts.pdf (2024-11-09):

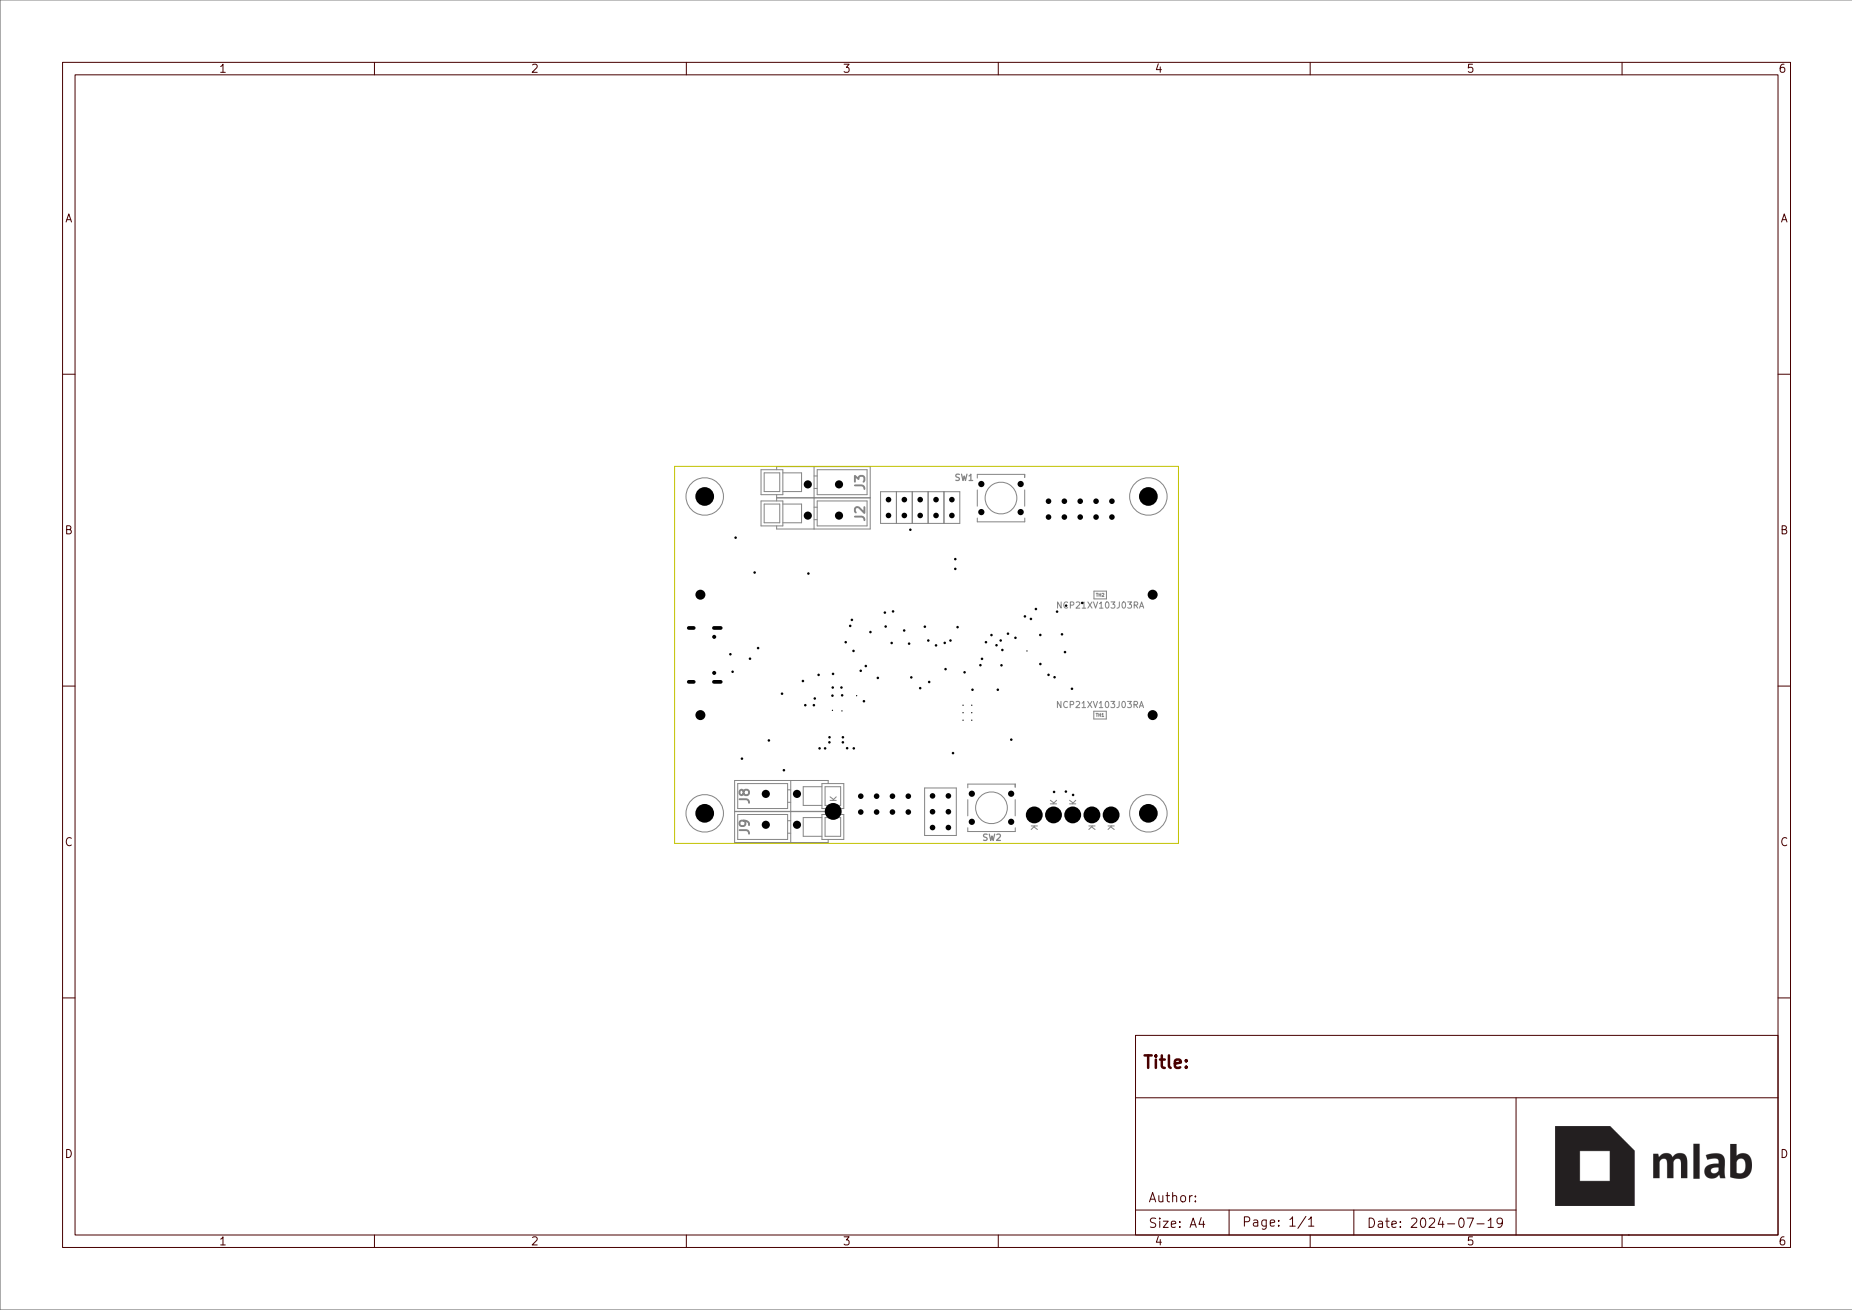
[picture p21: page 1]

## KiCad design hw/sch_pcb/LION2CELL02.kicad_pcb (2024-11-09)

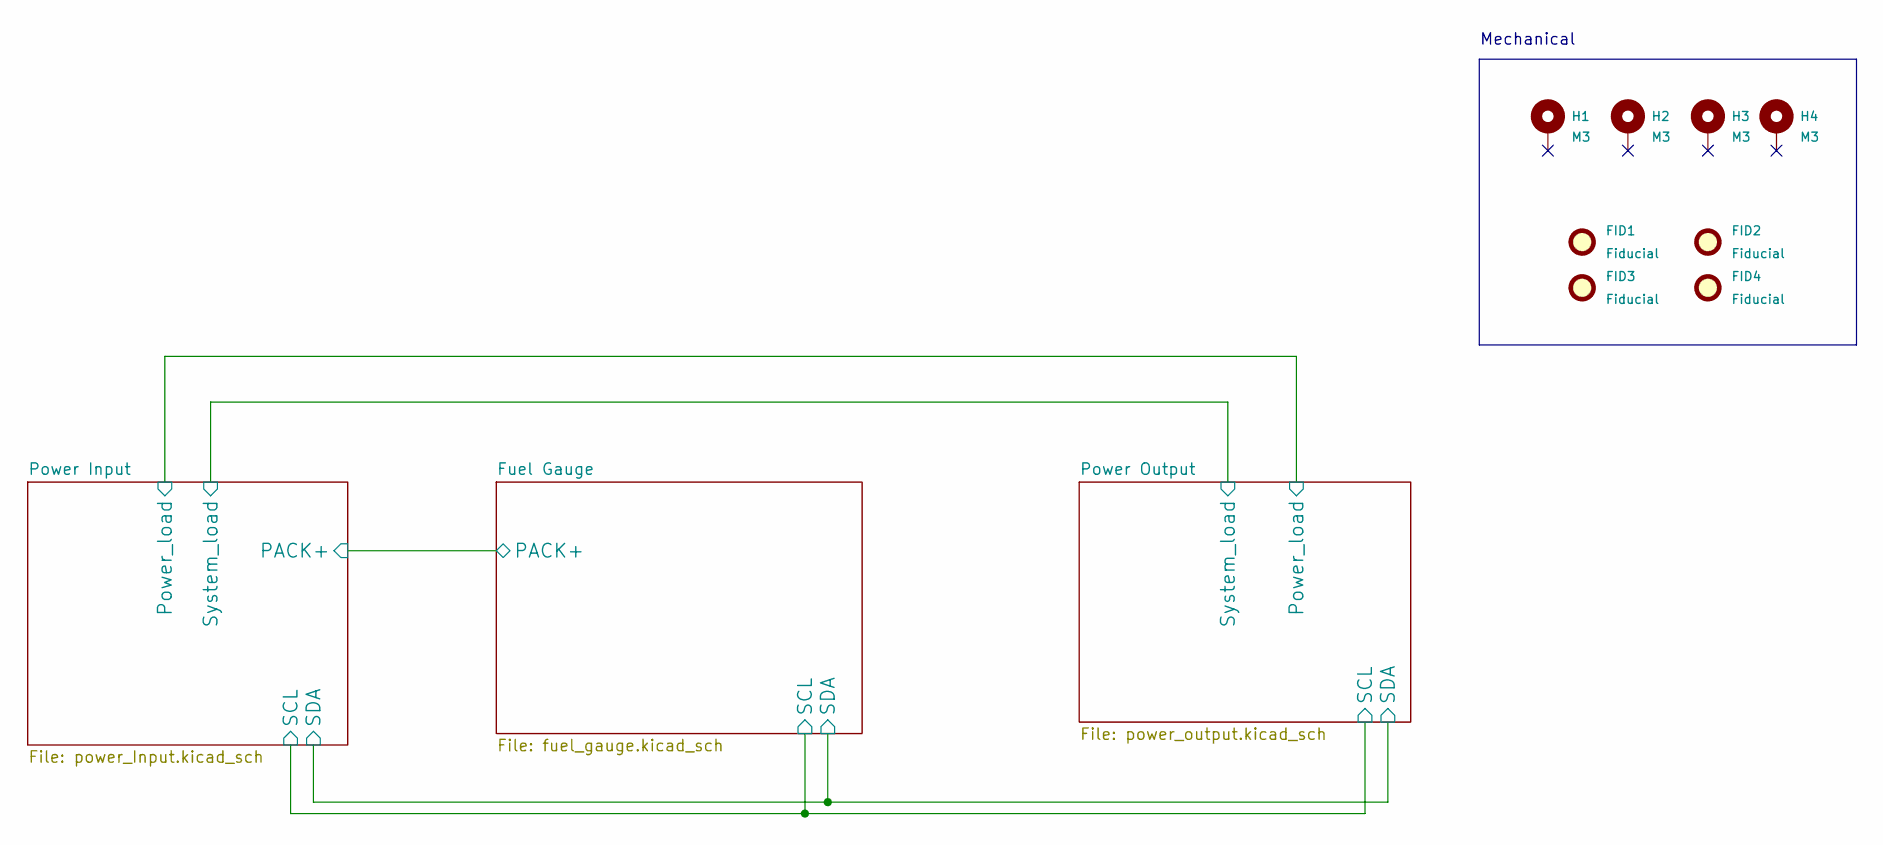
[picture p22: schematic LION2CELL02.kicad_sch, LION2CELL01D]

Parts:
FID1, FID2, FID3, FID4: Fiducial; Fiducial_1mm_Mask2mm
H1, H2, H3, H4: M3; MountingHole_3mm

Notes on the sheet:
Mechanical

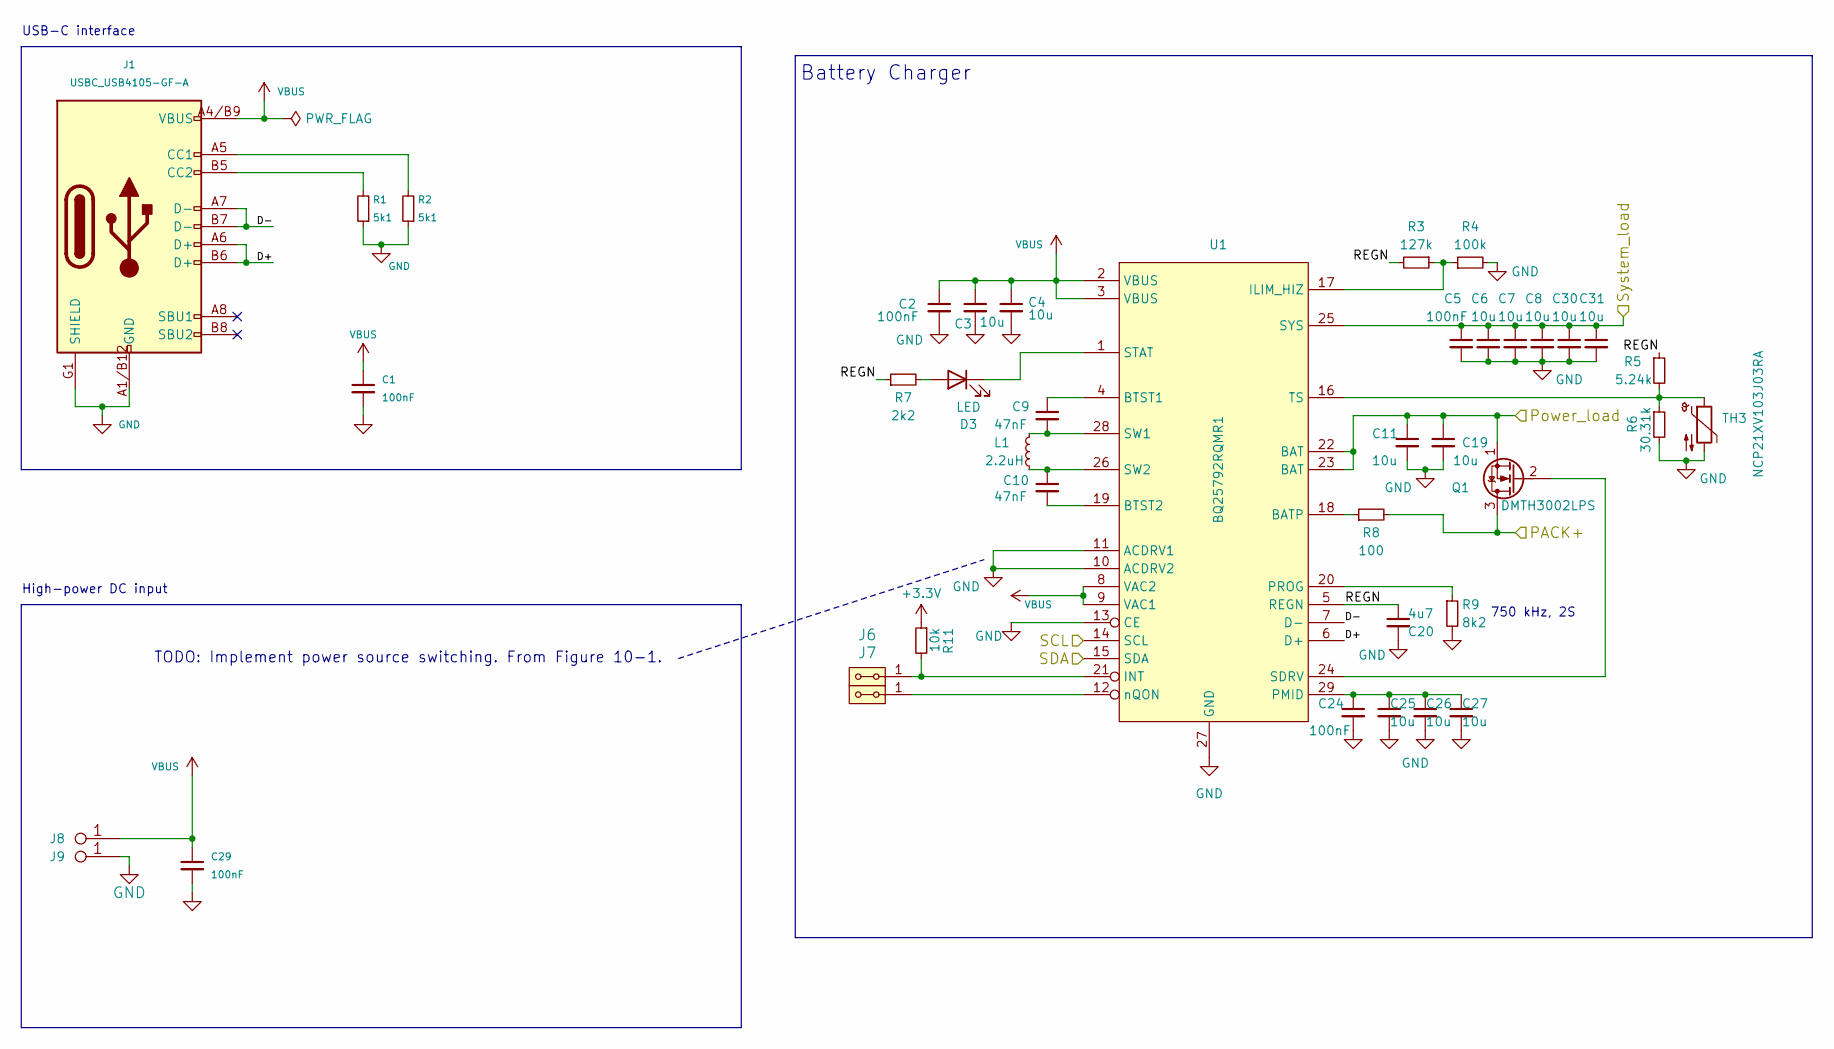
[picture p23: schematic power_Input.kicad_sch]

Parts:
C1, C2: 100nF; C_0805_2012Metric
C3, C4, C6, C7, C8, C11, C19, C25, C26, C27, C30, C31: 10u; C_0805_2012Metric
C5, C24: 100nF; C_0603_1608Metric
C9, C10: 47nF; C_0805_2012Metric
C20: 4u7; C_0805_2012Metric
C29: 100nF; C_0805_2012Metric; MPN C0805 1u
D3: LED; LED_1206
J1: USBC_USB4105-GF-A; USBC GCT_USB4105-GF-A; MPN USB4105-GF-A
J6, J7: HEADER_2x01_PARALLEL; Straight_2x01
J8, J9: CONN1_1; WAGO256
L1: 2.2uH; L_Vishay_IHLP-2020
Q1: DMTH3002LPS; D_POWERDI5060-8_6.0x5.1mm_P1.27mm
R1, R2: 5k1; R_0805_2012Metric
R3: 127k; R_0805_2012Metric
R4: 100k; R_0805_2012Metric
R5: 5.24k; R_0805_2012Metric
R6: 30.31k; R_0805_2012Metric
R7: 2k2; R_0805_2012Metric
R8: 100; R_0805_2012Metric
R9: 8k2; R_0805_2012Metric
R11: 10k; R_0805_2012Metric
TH3: NCP21XV103J03RA; R_0805_2012Metric
U1: BQ25792RQMR1; Texas_RQM0029A_VQFN-HR-28_4x4mm_P0.5mm

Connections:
+3.3V: R11.1; also elsewhere on the board
/Fuel Gauge/PACK+: Q1.3 (D), R8.2; also elsewhere on the board
/Fuel Gauge/SCL: U1.14 (SCL); also elsewhere on the board
/Fuel Gauge/SDA: U1.15 (SDA); also elsewhere on the board
/Power Input/D+: J1.A6 (D+), J1.B6 (D+), U1.6 (D+)
/Power Input/D-: J1.A7 (D-), J1.B7 (D-), U1.7 (D-)
/Power Input/Power_load: C11.1, C19.1, Q1.1 (S), U1.22 (BAT), U1.23 (BAT); also elsewhere on the board
/Power Input/REGN: C20.1, R3.2, R5.1, R7.1, U1.5 (REGN)
/Power Input/System_load: C5.1, C6.1, C7.1, C8.1, C30.1, C31.1, U1.25 (SYS); also elsewhere on the board
GND: C1.2, C2.2, C3.2, C4.2, C5.2, C6.2, C7.2, C8.2, C11.2, C19.2, C20.2, C24.2, C25.2, C26.2, C27.2, C29.2, C30.2, C31.2, J1.A1/B12 (GND), J1.B1/A12 (GND), J1.G1 (SHIELD), J1.G2 (SHIELD), J1.G3 (SHIELD), J1.G4 (SHIELD), J9.1, R1.1, R2.1, R4.2, R6.2, R9.2, TH3.2, U1.10 (ACDRV2), U1.11 (ACDRV1), U1.13 (CE), U1.27 (GND); also elsewhere on the board
unnamed: D3.2 (A), R7.2
unnamed: D3.1 (K), U1.1 (STAT)
unnamed: J1.A5 (CC1), R2.2
unnamed: J1.B5 (CC2), R1.2
unnamed: Q1.2 (G), U1.24 (SDRV)
unnamed: R8.1, U1.18 (BATP)
unnamed: C9.1, U1.4 (BTST1)
unnamed: C10.2, U1.19 (BTST2)
unnamed: R3.1, R4.1, U1.17 (ILIM_HIZ)
unnamed: J6.1, J6.2, R11.2, U1.21 (INT)
unnamed: C24.1, C25.1, C26.1, C27.1, U1.29 (PMID)
unnamed: R9.1, U1.20 (PROG)
unnamed: C9.2, L1.2, U1.28 (SW1)
unnamed: C10.1, L1.1, U1.26 (SW2)
unnamed: R5.2, R6.1, TH3.1, U1.16 (TS)
unnamed: J7.1, J7.2, U1.12 (nQON)
VBUS: C1.1, C2.1, C3.1, C4.1, C29.1, J1.A4/B9 (VBUS), J1.B4/A9 (VBUS), J8.1, U1.2 (VBUS), U1.3 (VBUS), U1.8 (VAC2), U1.9 (VAC1)

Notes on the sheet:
Battery Charger
High-power DC input
USB-C interface
750 kHz, 2S
TODO: Implement power source switching. From Figure 10-1.

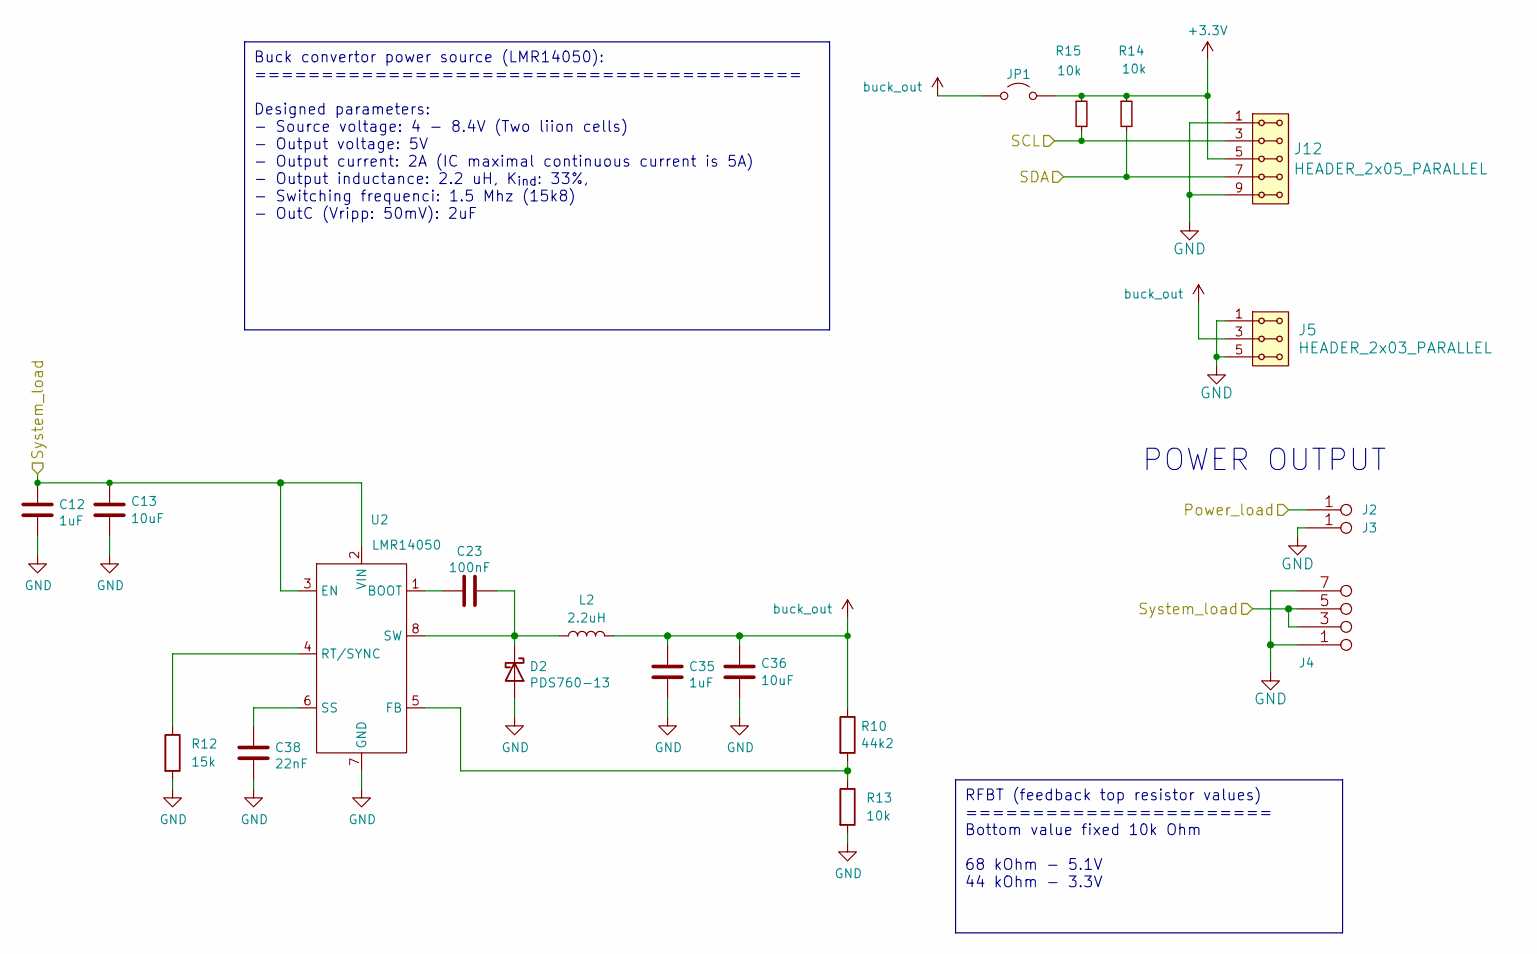
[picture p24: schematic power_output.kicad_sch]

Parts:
C12, C35: 1uF; C_0805_2012Metric
C13, C36: 10uF; C_0805_2012Metric
C23: 100nF; C_0805_2012Metric
C38: 22nF; C_0805_2012Metric
D2: PDS760-13; D_PowerDI-5
J2, J3: CONN1_1; WAGO256
J4: JUMP_4X2; Straight_2x04
J5: HEADER_2x03_PARALLEL; Straight_2x03
J12: HEADER_2x05_PARALLEL; Straight_2x05
JP1: Jumper_2_Open; Straight_2x01
L2: 2.2uH; L_Vishay_IHLP-2020
R10: 44k2; R_0805_2012Metric
R12: 15k; R_0805_2012Metric
R13, R14, R15: 10k; R_0805_2012Metric
U2: LMR14050; SOIC-8-1EP_3.9x4.9mm_P1.27mm_EP2.41x3.3mm_ThermalVias

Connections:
+3.3V: J12.5, J12.6, JP1.2 (B), R14.1, R15.1; also elsewhere on the board
/Fuel Gauge/SCL: J12.3, J12.4, R15.2; also elsewhere on the board
/Fuel Gauge/SDA: J12.7, J12.8, R14.2; also elsewhere on the board
/Power Input/Power_load: J2.1; also elsewhere on the board
/Power Input/System_load: C12.1, C13.1, J4.3 (4), J4.4, J4.5, J4.6 (5), U2.2 (VIN), U2.3 (EN); also elsewhere on the board
GND: C12.2, C13.2, C35.2, C36.2, C38.2, D2.2 (A), J3.1, J4.1 (2), J4.2, J4.7 (8), J4.8, J5.1, J5.2, J5.5, J5.6, J12.1, J12.2, J12.9, J12.10, R12.2, R13.2, U2.7 (GND), U2.9 (GND); also elsewhere on the board
unnamed: C23.2, D2.1 (K), L2.1, U2.8 (SW)
unnamed: C23.1, U2.1 (BOOT)
unnamed: R10.2, R13.1, U2.5 (FB)
unnamed: R12.1, U2.4 (RT/SYNC)
unnamed: C38.1, U2.6 (SS)
buck_out: C35.1, C36.1, J5.3, J5.4, JP1.1 (A), L2.2, R10.1

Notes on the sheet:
Buck convertor power source (LMR14050): ========================================= Designed parameters: - Source voltage: 4 - 8.4V (Two liion cells) - Output voltage: 5V - Output current: 2A (IC maximal continuous current is 5A) - Output inductance: 2.2 uH, K_{ind}: 33%, - Switching frequenci: 1.5 M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
RFBT (feedback top resistor values) ======================= Bottom value fixed 10k Ohm 68 kOhm - 5.1V 44 kOhm - 3.3V
POWER OUTPUT

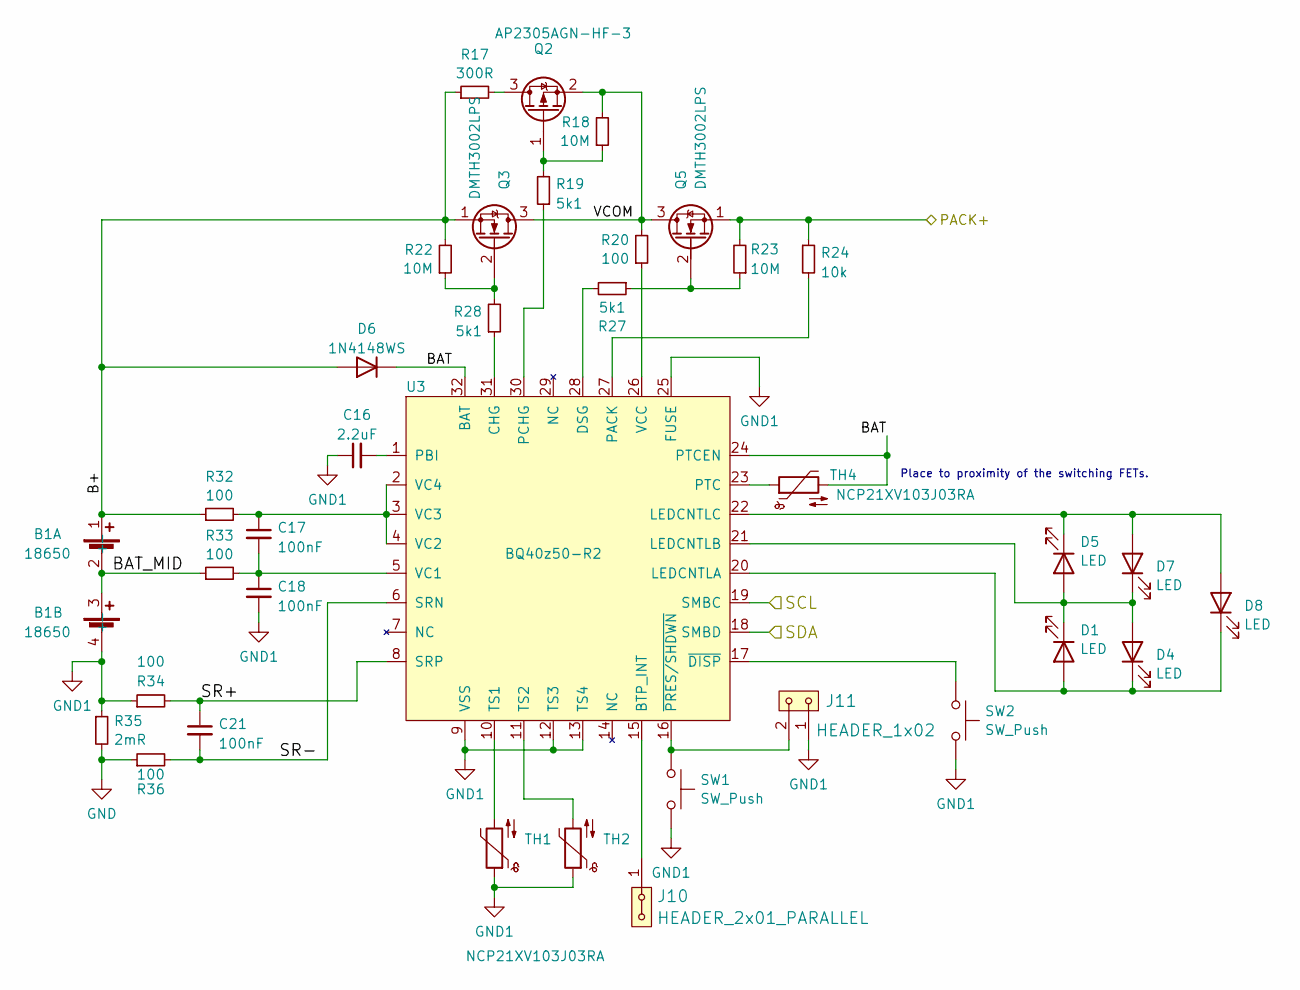
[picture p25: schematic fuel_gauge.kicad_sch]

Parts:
B1: 18650; BAT_BK-18650-PC4_no_screws
C16: 2.2uF; C_0805_2012Metric
C17, C18, C21: 100nF; C_0805_2012Metric; LCSC C1525
D1, D4, D5, D7, D8: LED; LED_1206
D6: 1N4148WS; D_0805_2012Metric
J10: HEADER_2x01_PARALLEL; Straight_2x01
J11: HEADER_1x02; Straight_2x01
Q2: AP2305AGN-HF-3; SOT-23
Q3, Q5: DMTH3002LPS; D_POWERDI5060-8_6.0x5.1mm_P1.27mm; Manufacturer_Part_Number DMT31M7LPS-13
R17: 300R; R_1206_3216Metric
R18, R22, R23: 10M; R_0805_2012Metric; LCSC C26082
R19, R27, R28: 5k1; R_0805_2012Metric; LCSC C25905
R20, R32, R33: 100; R_0805_2012Metric; LCSC C17408
R24: 10k; R_0805_2012Metric; LCSC C25744
R34, R36: 100; R_0805_2012Metric; LCSC C25076
R35: 2mR; R_2512_6332Metric
SW1, SW2: SW_Push; SW_PUSH_SMALL
TH1, TH2: NCP21XV103J03RA; R_0805_2012Metric; LCSC C279801
TH4: NCP21XV103J03RA; R_0805_2012Metric
U3: BQ40z50-R2; Texas_RSM0032A_VQFN-32-4.1x4.1-EP-1.4; LCSC C179743

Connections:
/Fuel Gauge/B+: B1.1 (+), D6.2 (A), Q3.1 (S), R17.1, R22.2, R32.1
/Fuel Gauge/BAT: D6.1 (K), TH4.2, U3.24 (PTCEN), U3.32 (BAT)
/Fuel Gauge/BAT_MID: B1.2 (-), B1.3 (+), R33.1
/Fuel Gauge/PACK+: Q5.1 (S), R23.2, R24.1; also elsewhere on the board
/Fuel Gauge/SCL: U3.19 (SMBC); also elsewhere on the board
/Fuel Gauge/SDA: U3.18 (SMBD); also elsewhere on the board
/Fuel Gauge/SR+: C21.1, R34.2, U3.8 (SRP)
/Fuel Gauge/SR-: C21.2, R36.2, U3.6 (SRN)
/Fuel Gauge/VCOM: Q2.2 (S), Q3.3 (D), Q5.3 (D), R18.2, R20.2
GND: R35.2, R36.1; also elsewhere on the board
GND1: B1.4 (-), C16.1, C18.2, J11.1, R34.1, R35.1, SW1.2, SW2.2, TH1.1, TH2.1, U3.9 (VSS), U3.12 (TS3), U3.13 (TS4), U3.25 (FUSE), U3.33 (PWRPD)
unnamed: D1.2 (A), D4.1 (K), D8.1 (K), U3.20 (LEDCNTLA)
unnamed: D1.1 (K), D4.2 (A), D5.2 (A), D7.1 (K), U3.21 (LEDCNTLB)
unnamed: D5.1 (K), D7.2 (A), D8.2 (A), U3.22 (LEDCNTLC)
unnamed: Q2.3 (D), R17.2
unnamed: Q2.1 (G), R18.1, R19.2
unnamed: Q3.2 (G), R22.1, R28.2
unnamed: Q5.2 (G), R23.1, R27.1
unnamed: J10.1, J10.2, U3.15 (BTP_INT)
unnamed: R28.1, U3.31 (CHG)
unnamed: R27.2, U3.28 (DSG)
unnamed: R24.2, U3.27 (PACK)
unnamed: C16.2, U3.1 (PBI)
unnamed: R19.1, U3.30 (PCHG)
unnamed: TH4.1, U3.23 (PTC)
unnamed: TH1.2, U3.10 (TS1)
unnamed: TH2.2, U3.11 (TS2)
unnamed: C17.2, C18.1, R33.2, U3.5 (VC1)
unnamed: C17.1, R32.2, U3.2 (VC4), U3.3 (VC3), U3.4 (VC2)
unnamed: R20.1, U3.26 (VCC)
unnamed: SW2.1, U3.17 (~DISP)
unnamed: J11.2, SW1.1, U3.16 (~PRES/SHDWN)

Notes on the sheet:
Place to proximity of the switching FETs.

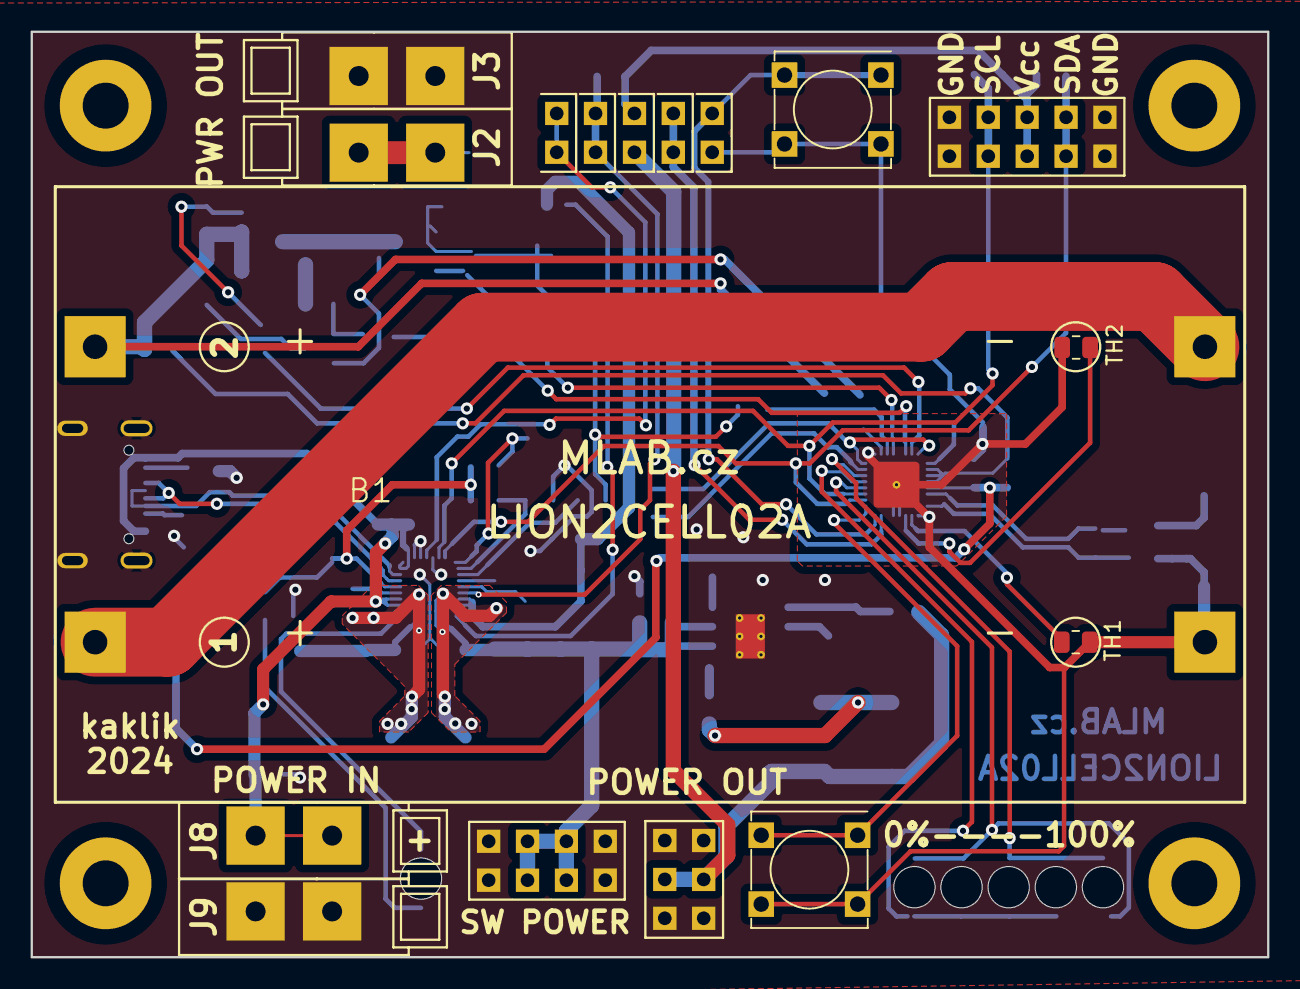
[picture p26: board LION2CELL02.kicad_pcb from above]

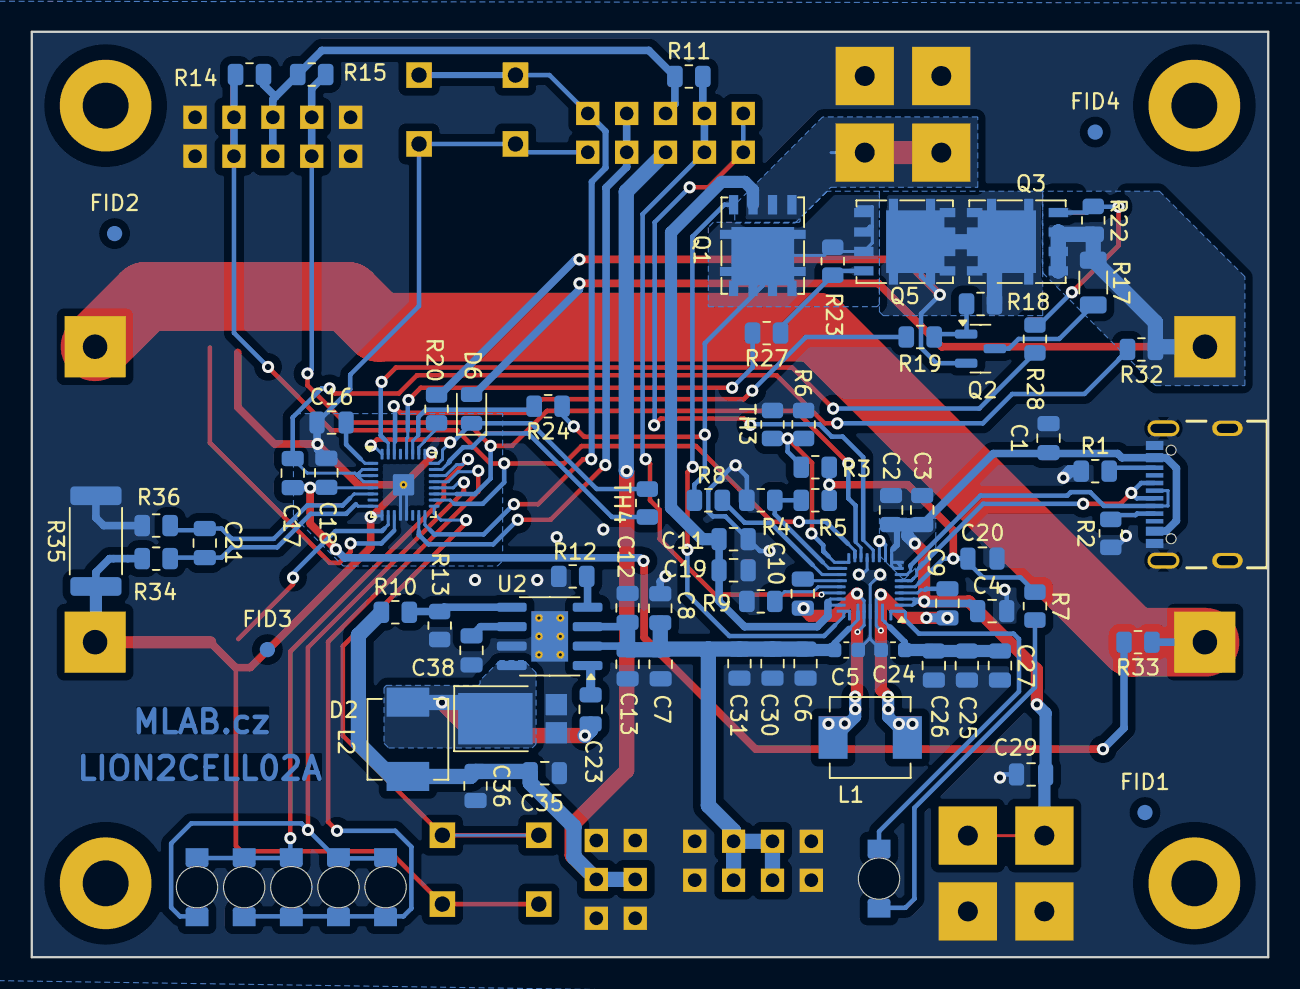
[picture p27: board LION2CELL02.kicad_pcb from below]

Board: 2 copper layers, 80.8 x 60.5 mm, 104 parts (83 on the bottom side), 61 nets.

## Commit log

2024-07-17 Initial work on the BMS module.
    [6x8MLAB_frame.scad, 6x8MLAB_frame.stl, LION2CELL02.kicad_pcb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]
2024-07-18 Initial work on battery charging.
    [LION2CELL02.kicad_sch, fuel_gauge.kicad_sch, power_Input.kicad_sch]
2024-07-19 work of the schematics of charger completed.
    [LION2CELL02.kicad_sch, power_Input.kicad_sch, power_output.kicad_sch]
2024-07-19 Fuel gauge schematics work done.
    [fuel_gauge.kicad_sch]
2024-07-19 Schematics work. PCB layout initial schematics import.
    [LION2CELL02.kicad_pcb, LION2CELL02.kicad_sch, fuel_gauge.kicad_sch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]
2024-07-20 Improve documentation.
    [LION2CELL02.kicad_pcb, fuel_gauge.kicad_sch]
2024-07-20 Update actions products
    [LION2CELL02-B_Adhesive.dxf, LION2CELL02-B_Courtyard.dxf, LION2CELL02-B_Cu.dxf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]
2024-07-20 Layout WiP.
    [LION2CELL02.kicad_pcb, fuel_gauge.kicad_sch, power_Input.kicad_sch]
2024-07-21 Partially routed PCB.
    [LION2CELL02.kicad_pcb, LION2CELL02.kicad_sch, fuel_gauge.kicad_sch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]
2024-07-21 Routed few aditional nets Battery mid-point zone connection changed to a track with special net class.
    [LION2CELL02.kicad_pcb, fuel_gauge.kicad_sch]
2024-07-21 PCB routing WiP.
    [LION2CELL02.kicad_pcb, fuel_gauge.kicad_sch]
2024-07-21 Routed another tracks.
    [LION2CELL02.kicad_pcb, fuel_gauge.kicad_sch]
2024-07-21 The first completely routed nets.
    [LION2CELL02.kicad_pcb]
2024-07-21 Adding output voltage switching regulator.
    [LION2CELL02.kicad_pcb, LION2CELL02.kicad_sch, power_output.kicad_sch]
2024-07-22 Minimizing output regulator components count.
    [LION2CELL02.kicad_pcb, power_output.kicad_sch]
2024-07-22 update power-output schematic
    [power_output.kicad_sch]
2024-07-22 Reduce complexity of layout.
    [LION2CELL02.kicad_pcb]
2024-07-22 Cleanup routing. Adding 5V output connector.
    [LION2CELL02.kicad_pcb]
2024-07-22 Syncing board with schematics. Roughly placing the switching regulator.
    [LION2CELL02.kicad_pcb, power_Input.kicad_sch, power_output.kicad_sch]
2024-07-22 Routed switching regulator Starting of layout cleanup. Uniforming of charger and switching regulator inductors.
    [LION2CELL02.kicad_pcb, power_Input.kicad_sch, power_output.kicad_sch]
2024-07-23 Uniforming track width Cleanup layout. Fix high-current paths Create copper-pours to high-current areas.
    [LION2CELL02.kicad_pcb]
2024-07-23 Correct positioning of FIDUs Fix silkscreen texts.
    [LION2CELL02.kicad_pcb]
2024-07-24 USB data lines layout improvement. Zones definitions for improving noise imunity.
    [LION2CELL02.kicad_pcb, fuel_gauge.kicad_sch, power_Input.kicad_sch]
2024-07-24 Resolve DRC issues. Update footprints. Improve silkscreen.
    [LION2CELL02.kicad_pcb, power_output.kicad_sch]
2024-07-24 Update USTids.
    [LION2CELL02.kicad_pcb, fuel_gauge.kicad_sch, power_Input.kicad_sch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]
2024-07-24 Fix missing assigments.
    [LION2CELL02.kicad_pcb, fuel_gauge.kicad_sch]
2024-07-24 Fix whitespaces around USTids.
    [fuel_gauge.kicad_sch, power_Input.kicad_sch]
2024-07-26 Fix fab layer.
    [LION2CELL02.kicad_pcb]
2024-08-08 Fix components identification.
    [fuel_gauge.kicad_sch, power_Input.kicad_sch, power_output.kicad_sch]
2024-08-08 Update PCB from schematics.
    [LION2CELL02.kicad_pcb]
2024-09-18 Adding initial configuration for Murata cells.
    [Murata_VTC6_LION2CELL02.gg.csv]
2024-11-08 Move reference to avoid collision.
    [power_Input.kicad_sch]
2024-11-09 Update documentation. Add Tindie listing.
    [LION2CELL02.kicad_pcb]
